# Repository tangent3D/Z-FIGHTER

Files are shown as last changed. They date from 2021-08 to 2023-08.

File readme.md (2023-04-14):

### Description
Z-FIGHTER is a Z80 hobby computer loosely based on [Grant Searle's CP/M on breadboard](http://searle.x10host.com/cpm/index.html "Grant Searle's CP/M on breadboard") project. As a fully assembled unit in its custom 3D-printed enclosure, Z-FIGHTER has a handheld-style form factor with front panel accessories intended for user-created software and games. Connected via serial to a computer or terminal, Z-FIGHTER can be used to enjoy a full CP/M 2.2 environment or Microsoft BASIC in ROM. Finally, a parallel port and external CPU control pins are provided to the user for hardware hacking and expansion.

### Specifications
- Z80 CPU @ 7.3728MHz
- CompactFlash interface for CP/M 2.2 operating system and file storage
- Z80 SIO/0 with dual 115200 bps RS-232 ports
- Jumper-selectable optional clock oscillator (X2) for SIO/0 port B (e.g.  614.4 KHz/64 for 9600 bps)
- Jumper-selectable RS-232 CTS flow control
- i8255 PPI-based parallel port reserved for front panel accessory daughterboard
- i8255 PPI-based user parallel port
- 512K ROM with external DIP-3 switches for manual ROM paging and ATF22V10C SPLD for memory map customization
- USB type-B power connector
- DS1233 supervisory circuit
- Optional jumpers to supply +5V to pin 9 on RS-232 ports (non-standard, for use at user's own risk)
- External CPU control header exposing #INT, #NMI, #WAIT, #RESET, system clock and SIO Ch. B clock signals

### Accessory board specifications
- 8x Cherry MX key switches
- ST7920 128x64 LCD module with software-controllable backlight
- Electromagnetic buzzer (CPU-controlled)

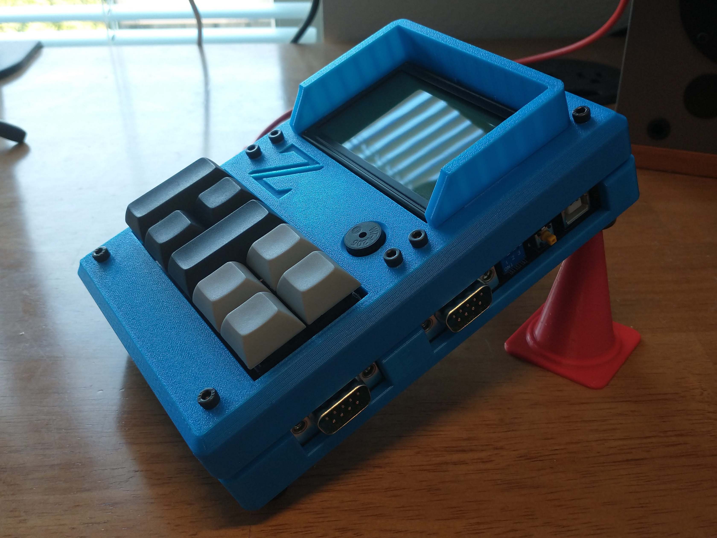
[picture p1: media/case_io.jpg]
Z-FIGHTER


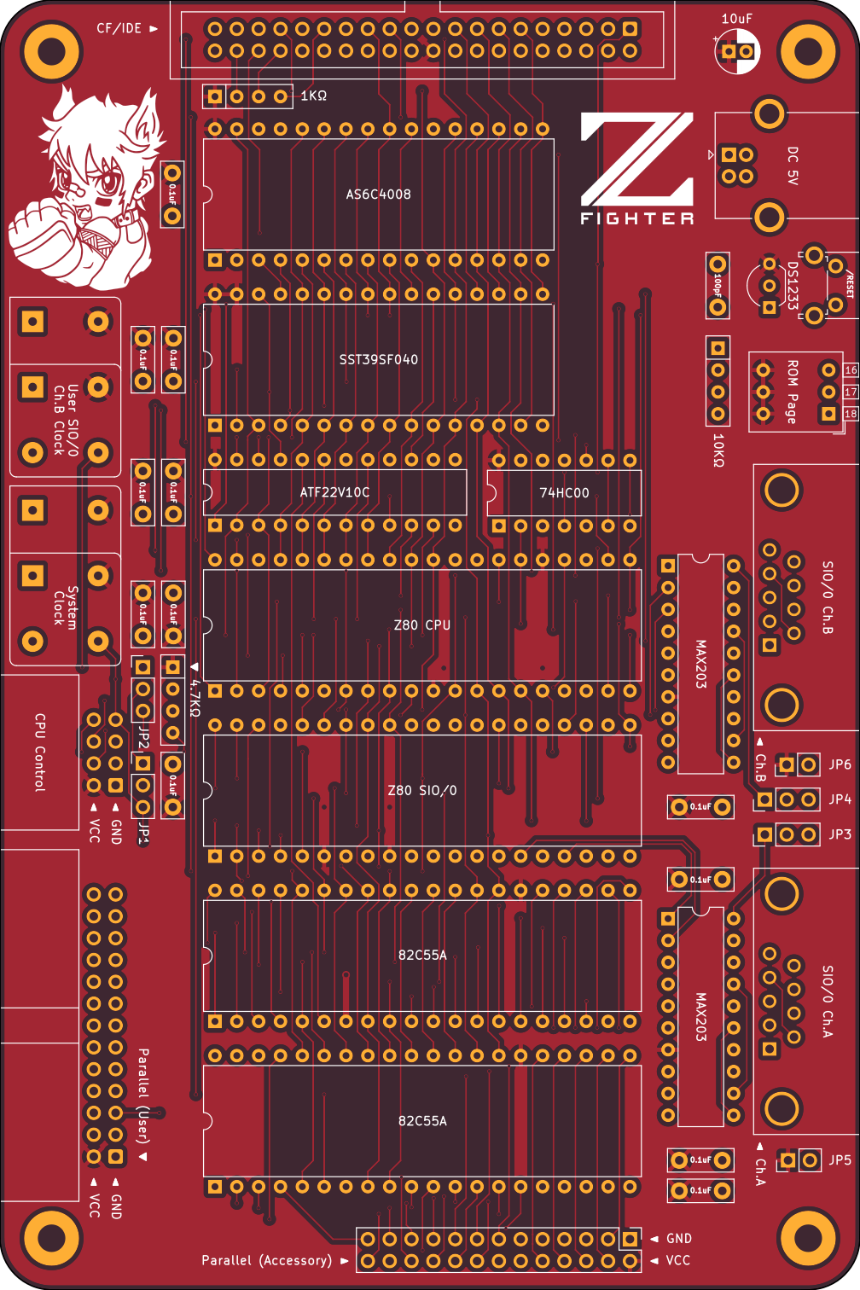
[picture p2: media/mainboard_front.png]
Z-FIGHTER Mainboard Z-FIGHTER mainboard


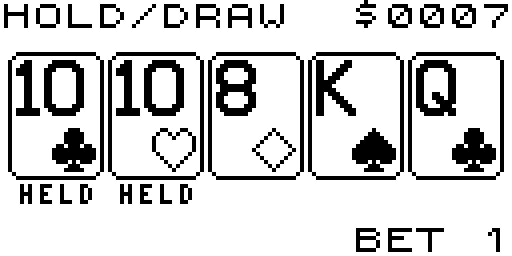
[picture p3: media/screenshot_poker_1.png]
Poker Z-FIGHTER poker game


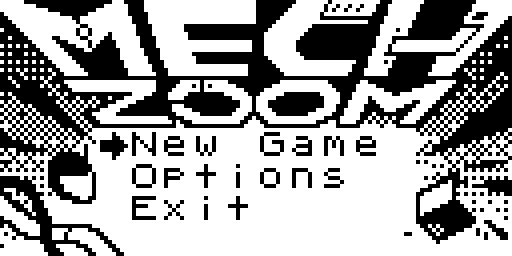
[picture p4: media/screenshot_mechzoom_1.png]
Mechzoom Z-FIGHTER 'Mechzoom' game


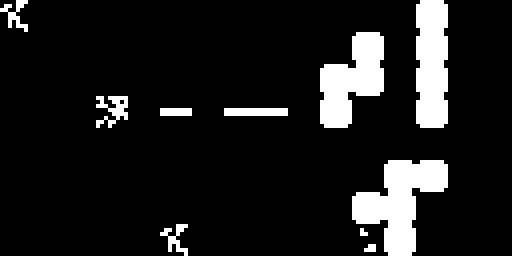
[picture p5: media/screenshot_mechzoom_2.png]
Mechzoom Z-FIGHTER 'Mechzoom' game


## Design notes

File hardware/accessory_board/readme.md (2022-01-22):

## Z-FIGHTER Front Panel Accessory Board

[PCB schematic](../../media/schematic_accessory_board.pdf)

[PCB layout](../../media/layout_accessory_board.pdf)

## Bill of Materials
|Part Description|Quantity|Mouser #|Link
|--|--|--|--|
|Cherry MX switches (PCB mount)|8|540-MX1A-G1NW|[Mouser](https://www.mouser.com/ProductDetail/?qs=F5EMLAvA7IAf8LDkSr80OA%3D%3D)
|Resistor Network 10K 9Pin Bussed|1|652-4609H-1LF-10K|[Mouser](https://www.mouser.com/ProductDetail/Bourns/4609H-101-103LF?qs=sGAEpiMZZMujMHSoaAZeGdkD0yBqu0zL)
|WT-1205 electromagnetic buzzer|1|539-PB1224PE-05Q|[Mouser](https://www.mouser.com/ProductDetail/?qs=yTNxYlKScpyeBlcw7zrVEw%3D%3D)
|1N5817 Schottky diode|1|511-1N5817|[Mouser](https://www.mouser.com/ProductDetail/?qs=JV7lzlMm3yKNnxZdh%252BSMnw%3D%3D)
|BC337 NPN transistor|2|512-BC33725TAR|[Mouser](https://www.mouser.com/ProductDetail/?qs=u2B728UsA6qKwH1IAisoWA%3D%3D)
|1/4W 820 Ohm 5% resistor|1|603-CFR-25JT-52-820R|[Mouser](https://www.mouser.com/ProductDetail/?qs=KUIzHt%2Fe91nf0zePCO9VQg%3D%3D)
|1/4W 680 Ohm 5% resistor|1|603-CFR-25JB-52-680R|[Mouser](https://www.mouser.com/ProductDetail/?qs=oypCK0zG327gSAdGYp%2FJTg%3D%3D)
|1x20 right angle header|1|649-1012937992002BLF|[Mouser](https://www.mouser.com/ProductDetail/?qs=0lQeLiL1qybxcF3pstck9w%3D%3D)
|ST7920 128x64 Graphic LCD|1||[BuyDisplay](https://www.buydisplay.com/3-3v-5v-graphic-display-128x64-serial-lcd-display-st7920)
|20mm vertical double row breakaway header|1||[Amazon](https://www.amazon.com/uxcell-Straight-Connector-Arduino-Prototype/dp/B07DJY3FRJ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)
|Right-angle header (female)|1||[Amazon](https://www.amazon.com/Yohii-Female-Header-2-54mm-Connector/dp/B07P1R9CGT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)
|DSA profile 2U keycap|2||[Pimp My Keyboard](https://pimpmykeyboard.com/dsa-2-space-pack-of-4/)
|DSA profile 1U keycap|6||[Pimp My Keyboard](https://pimpmykeyboard.com/dsa-1-space-pack-of-10/)
|Cherry PCB snap-in 2U stabilizer|2||[Amazon](https://www.amazon.com/dp/B085T8QZJC/ref=cm_sw_r_tw_dp_V3VNQRQ0CPQBPXNV3A6B?_encoding=UTF8&psc=1)

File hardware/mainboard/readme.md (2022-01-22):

## Z-FIGHTER Mainboard

[PCB schematic](../../media/schematic_mainboard.pdf)

[PCB layout](../../media/layout_mainboard.pdf)

## Bill of Materials
|Part Description|Quantity|Mouser #|Link
|--|--|--|--|
Z84C0008PEG Z80 CPU|1|692-Z84C0008PEG|[Mouser](https://www.mouser.com/ProductDetail/?qs=1C6%2FyOstnVvOWPsPt2TcAQ%3D%3D)
AS6C4008-55PCN 512K x8 SRAM|1|913-AS6C4008-55PCN|[Mouser](https://www.mouser.com/ProductDetail/?qs=E5c5%252Bmu3i3%252BMOyro1Tlhzg%3D%3D)
SST39SF040-70-4C-PHE 512K x8 EEPROM|1|804-39SF0407CPHE|[Mouser](https://www.mouser.com/ProductDetail/?qs=YClUa%252B2dcx1pgizrqJ6nyQ%3D%3D)
82C55A Programmable Peripheral Interface|2||[Jameco](https://www.jameco.com/z/82C55A-Major-Brands-IC-82C55A-CPU-PERIPHERAL-INTERFACE-8MHZ-DIP-40-pin_52417.html)
MAX203EPP +5V RS-232 Transceiver|2|700-MAX203EPPG36|[Mouser](https://www.mouser.com/ProductDetail/?qs=CDqwynd4ZNogpJr0Fmpb1w%3D%3D)
USB 2.0 RA Receptacle Type B|1|530-SS-52300-001|[Mouser](https://www.mouser.com/ProductDetail/?qs=gZXFycFWdAM098VuPZGg2w%3D%3D)
Resistor Network 10K 4Pin Bussed|1|652-4604X-1LF-10K|[Mouser](https://www.mouser.com/ProductDetail/?qs=jXOqZ2xt48NO%2FqYoJux7tg%3D%3D)
DE-9 R/A male connector|2|806-K22X-E9P-N-99|[Mouser](https://www.mouser.com/ProductDetail/?qs=SY6bF4iPirTJ1N%2FB520%252B5Q%3D%3D)
Resistor Network 1K 4Pin Bussed|1|652-4604X-1LF-1K|[Mouser](https://www.mouser.com/ProductDetail/?qs=xtl3rb8zXsvZ4tyOouOFIw%3D%3D)
Ceramic Disc Capacitor 100pF|1|594-D101K20Y5PL63L6R|[Mouser](https://www.mouser.com/ProductDetail/?qs=GtWgGqLahXfZ4CSgyYo67w%3D%3D)
40P 2R male vertical box header|1|538-70246-4004|[Mouser](https://www.mouser.com/ProductDetail/?qs=g5f4E6w8l8h7b35ebEIf2w%3D%3D)
Tactile Switches R/A 6X6 6.15mm BTN|1|653-B3F-3152|[Mouser](https://www.mouser.com/ProductDetail/?qs=Pjd0UV7BHP%252BLeRBK3ENKog%3D%3D)
Socket OSCILLATOR FULL 4PIN|2|535-1107741|[Mouser](https://www.mouser.com/ProductDetail/?qs=WZRMhwwaLl%2FApwqojhfzdA%3D%3D)
ATF22V10C EEPLD|1|556-AF22V10C15PU|[Mouser](https://www.mouser.com/ProductDetail/?qs=2mdvTlUeTfCr46ZvfjTtAg%3D%3D)
Supervisory Circuits 5V EconoReset|1|700-DS1233-5|[Mouser](https://www.mouser.com/ProductDetail/?qs=0Y9aZN%252BMVCWOcj0LQZHuFQ%3D%3D)
Standard Clock Oscillators DIP-14 5V 7.3728MHz|1|520-TCF737-X|[Mouser](https://www.mouser.com/ProductDetail/?qs=GxOUx7aO6nw6OhbIEx8owA%3D%3D)
SN74HC00|1|595-SN74HC00AN|[Mouser](https://www.mouser.com/ProductDetail/?qs=6ZVwTuetbD7YqMbSpl34ug%3D%3D)
Z84C4010PEG Z80 SIO/0|1|692-Z84C4010PEG|[Mouser](https://www.mouser.com/ProductDetail/?qs=ZNtr8jqNHF4vszdb5PeVGw%3D%3D)
.100 Shunt|4|200-SNT100BKGH|[Mouser](https://www.mouser.com/ProductDetail/?qs=92ilVni64gz8scrxywNMxw%3D%3D)
3 POS DIP switch R/A|1|490-DS02C-254-1L03BE|[Mouser](https://www.mouser.com/ProductDetail/?qs=wnTfsH77Xs4jkggh8giIBw%3D%3D)
Headers & Wire Housings 26P R/A|1|517-30326-5002|[Mouser](https://www.mouser.com/ProductDetail/?qs=QV10cN0MjFuwK57KknWtBg%3D%3D)
10uF radial electrolytic capacitor|1|667-ECA-1EM100I|[Mouser](https://www.mouser.com/ProductDetail/?qs=rMMd5vBiahoPyQAc8NWEpA%3D%3D)
Socket 40P DIP|4|649-DILB40P223TLF|[Mouser](https://www.mouser.com/ProductDetail/?qs=dNsYR%2FH0PyPZ7Cx3x%252BXI2w%3D%3D)
Socket 32P DIP|2|649-DILB32P223TLF|[Mouser](https://www.mouser.com/ProductDetail/?qs=dNsYR%2FH0PyPAfvGxulPprw%3D%3D)
Socket 20P DIP|2|517-4820-3004-CP|[Mouser](https://www.mouser.com/ProductDetail/?qs=IGgAdOvCTsThtp8UbkGeUw%3D%3D)
Socket 14P DIP|1|517-4814-3000-CP|[Mouser](https://www.mouser.com/ProductDetail/?qs=IGgAdOvCTsSwgxfUvPVZeg%3D%3D)
Socket 24P DIP|1|649-DILB24P-224TLF|[Mouser](https://www.mouser.com/ProductDetail/?qs=cTNRJjk9LRekdjb2T7GbOg%3D%3D)
Ceramic capacitor 0.1uF 50V 5mm|12|594-K104K15X7RF53H5|[Mouser](https://www.mouser.com/ProductDetail/?qs=sYfpZ29HcUSlgH5bSUHkYw%3D%3D)
Resistor Network 4.7K 4Pin Bussed|1|652-4604X-1LF-4.7K|[Mouser](https://www.mouser.com/ProductDetail/?qs=10P5Hhl%252BD79Zc7vt0%2Fhnuw%3D%3D)
26P 2R vertical female header|1|855-M20-7831346|[Mouser](https://www.mouser.com/ProductDetail/?qs=Jph8NoUxIfWtokGFIxN9SQ%3D%3D)
1x3P vertical pin header|4|649-68000-403H|[Mouser](https://www.mouser.com/ProductDetail/?qs=eanFghet1JNqC%2F0Iz%252BuUPw%3D%3D)
1x2P vertical pin header|2|649-68000-402HLF|[Mouser](https://www.mouser.com/ProductDetail/?qs=Jhn0v8ulSDtl9VR1zMrdxQ%3D%3D)
8P R/A male box header|1|710-61200821721|[Mouser](https://www.mouser.com/ProductDetail/?qs=PhR8RmCirEb56BXUsQNR%2FQ%3D%3D)
M3 standoff (20mm)|4||[Amazon](https://www.amazon.com/dp/B07PK23VC4/ref=cm_sw_r_tw_dp_NGRJ3TRHWGEE7J0RGDNS?_encoding=UTF8&psc=1)
M3 socket head cap screw|12||[Amazon](https://www.amazon.com/dp/B078V3YCF6/ref=cm_sw_r_tw_dp_TQ4HJWWVDEA1XZR15HDK?_encoding=UTF8&psc=1)
M3 nut|4||[Amazon](https://www.amazon.com/dp/B078V3YCF6/ref=cm_sw_r_tw_dp_TQ4HJWWVDEA1XZR15HDK?_encoding=UTF8&psc=1)
(Optional) M3 rubber feet (D12 x 10 x H7mm)|4||[Amazon](https://www.amazon.com/dp/B07LF1J7ZB/ref=cm_sw_r_tw_dp_JDTK9C1A8TC8FPBZZV7F?_encoding=UTF8&psc=1)

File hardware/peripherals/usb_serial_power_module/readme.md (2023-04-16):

USB serial adapter with software-controllable pin 9 +5V. Not adherent to RS-232 standard. For use with Z-FIGHTER only. 

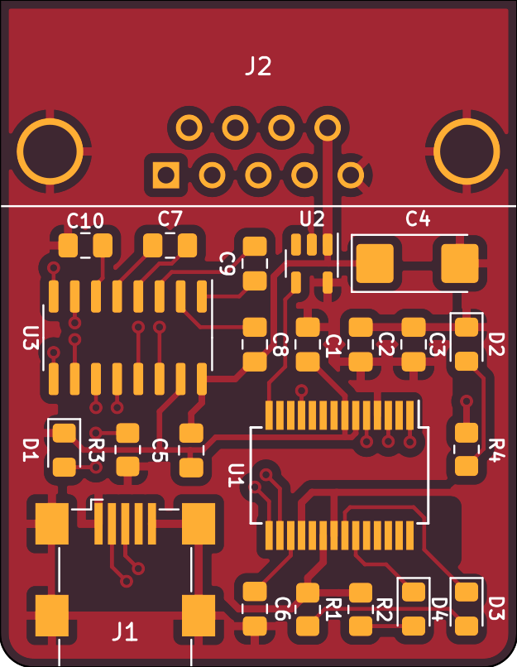
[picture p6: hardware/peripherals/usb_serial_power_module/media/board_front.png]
Module front


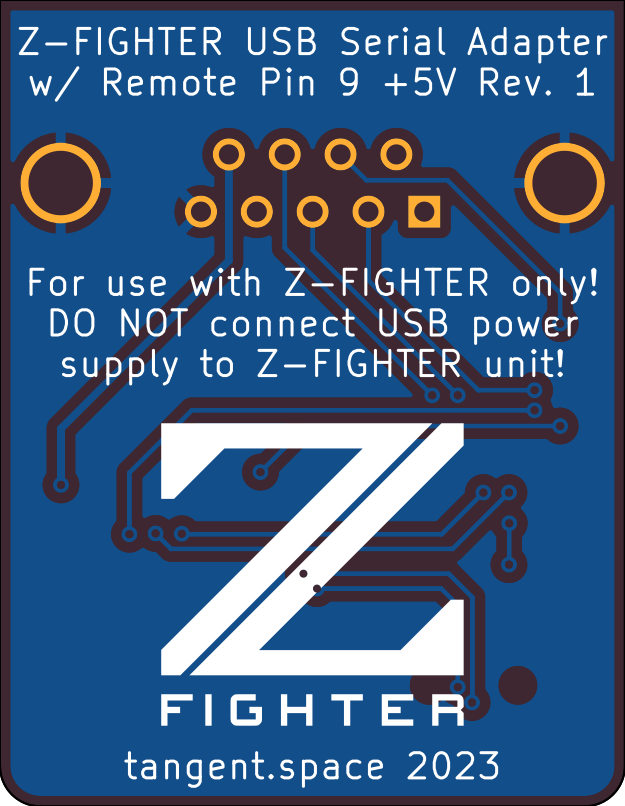
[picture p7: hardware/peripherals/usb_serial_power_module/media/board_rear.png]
Module rear


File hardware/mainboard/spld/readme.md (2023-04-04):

## Z-FIGHTER's Programmable Logic Device

An Atmel ATF22V10C-15PU SPLD is responsible for producing all chip select logic for Z-FIGHTER. An EEPROM burner is required to program the SPLD with a fuse map.

By default, Z-FIGHTER's memory map is configured as 32K ROM (0000h-7FFFh) and 32K RAM (8000h-FFFFh). ROM is disabled when an I/O write is executed on port 38h. RAM will thereafter use the entire 64K memory map until system reset.

A 3-position DIP switch (connected to EEPROM A18, A17, A16) will manually page the 512K EEPROM, affording the user eight bootable ROMs to be installed on the system. All ROMS should be placed at base addresses of 0000h, 10000h, ..., 70000h.

__Note for advanced users:__ The aforementioned DIP switch is likewise connected to the SPLD. Using combinational logic with EEPROM A18-A16 and Z80 address bus lines A15-A13, custom memory maps per each selected EEPROM page can be defined in chunks of 8K, e.g. 56K ROM/8K RAM.[^1] Care should be taken that ROMs are compiled to use the intended memory map.

Fuse maps can be compiled using [GALasm](https://github.com/daveho/GALasm).

[^1]: Mainboard revision 2d and later. In prior revisions, line A13 is not connected as an SPLD input.

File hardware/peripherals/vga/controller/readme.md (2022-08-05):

## Z-FIGHTER VGA Controller

[Project Notes](https://tangent.space/vga.htm)

[PCB schematic](../../../../media/schematic_vga_controller.pdf)

[PCB layout (Front)](../../../../media/layout_vga_controller_front.pdf)

[PCB layout (Back)](../../../../media/layout_vga_controller_back.pdf)

## Bill of Materials
|Reference|Description|Mouser #|Link
|--|--|--|--|
U1|74HC241||
R1,R2|Resistor, 1KΩ, 1/4W||
RN1,RN2|Resistor Array, Bussed, 10KΩ, 4x, SIP-5||
C1|Capacitor, 0.1uF, 5mm||
Q1|BC547, TO-92||
SW1 - SW8|Switch, Omron B3F-4050||
J1|DE-9, Female, R/A||

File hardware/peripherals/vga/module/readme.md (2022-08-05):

## Z-FIGHTER VGA Module

[Project Notes](https://tangent.space/vga.htm)

[PCB schematic](../../../../media/schematic_vga_module.pdf)

[PCB layout](../../../../media/layout_vga_module.pdf)

## Bill of Materials
|Reference|Description|Mouser #|Link
|--|--|--|--|
U1,U2|74HC4040||
U3,U4|GAL16V8||
U5,U6,U12,U13,U14|74HC541||
U7|74HC00||
U8|74HC04||
U9|74HC74||
U10|74HC165||
U11|AS6C6264||
X1|25.175 MHz Oscillator, DIP8/DIP14||
Q1|BC547, TO-92||
R1 - R3|220Ω Resistor, 1/4W||
R4 - R8|75Ω Resistor, 1/4W||
R9,R10|1KΩ Resistor, 1/4W||
C1,C2,C3,C6,C7|470pF Capacitor, Ceramic, 5mm||
C4,C5|22pF Capacitor, Ceramic, 5mm||
C8 - C22|0.1uF Capacitor, Ceramic, 5mm||
J1|26P Female Header, Vertical||
J2|8P Female Header, Vertical||
J3|DE-15 Female R/A||
J4,J5|DE-9 Male R/A||
SW1|DIP Switch, 3x, 7.62mm||
JP1|Jumper, 2.54mm, Vertical||




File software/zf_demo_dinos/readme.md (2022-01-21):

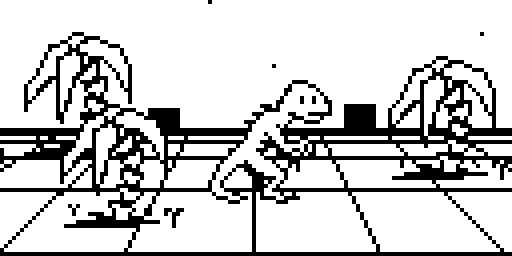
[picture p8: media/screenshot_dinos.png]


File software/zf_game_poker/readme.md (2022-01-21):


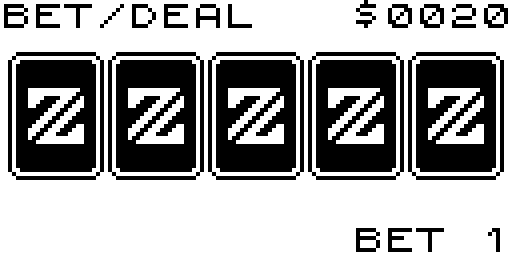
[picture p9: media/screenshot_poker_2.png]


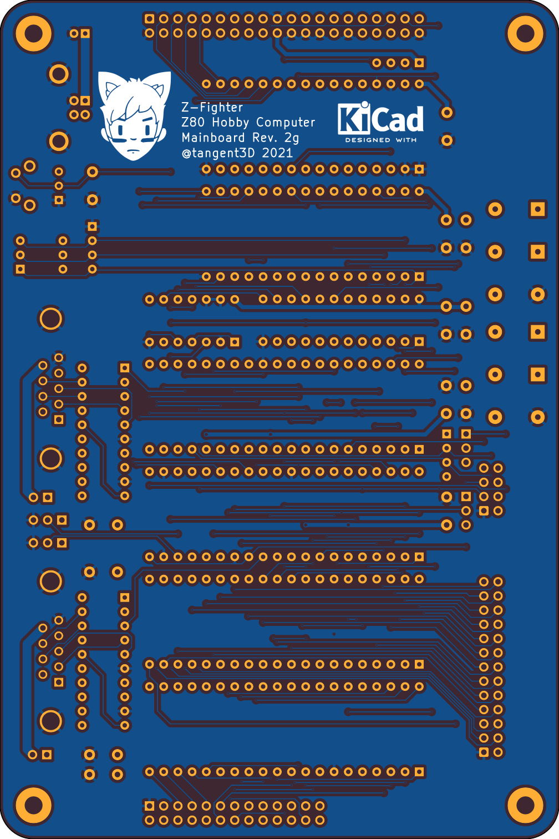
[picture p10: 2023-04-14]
media/mainboard_rear.png

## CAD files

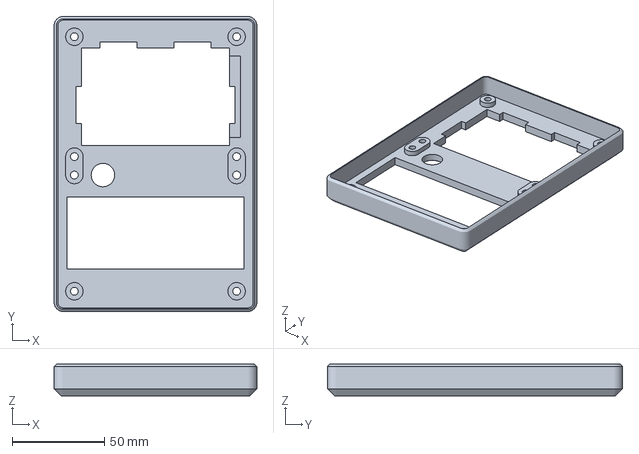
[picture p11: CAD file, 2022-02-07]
hardware/case/3mf/Z-FIGHTER_Case_Front.3mf
110.0 x 160.0 x 17.2 mm

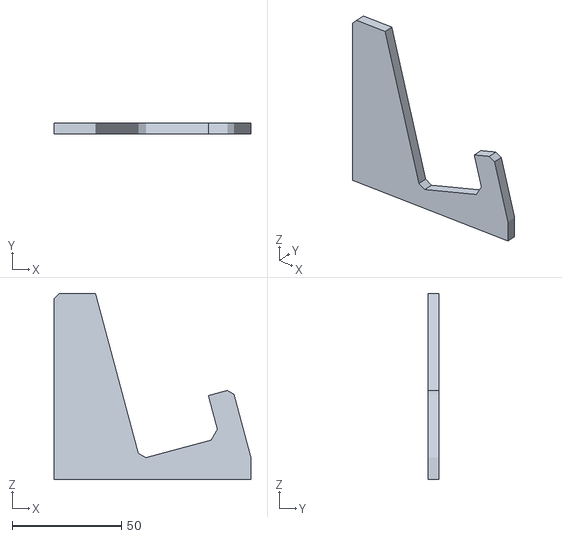
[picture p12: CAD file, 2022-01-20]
hardware/case/stl/Z-FIGHTER_Stand_Side.STL
90.0 x 5.00 x 85.0

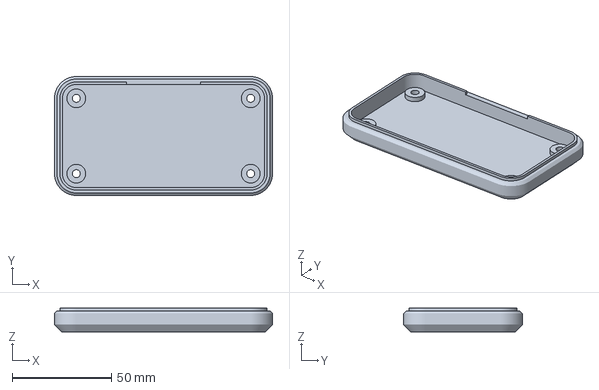
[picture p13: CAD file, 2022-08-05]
hardware/peripherals/vga/controller/case/3mf/Z-FIGHTER_Controller_Rear.3mf
110.0 x 60.0 x 12.1 mm

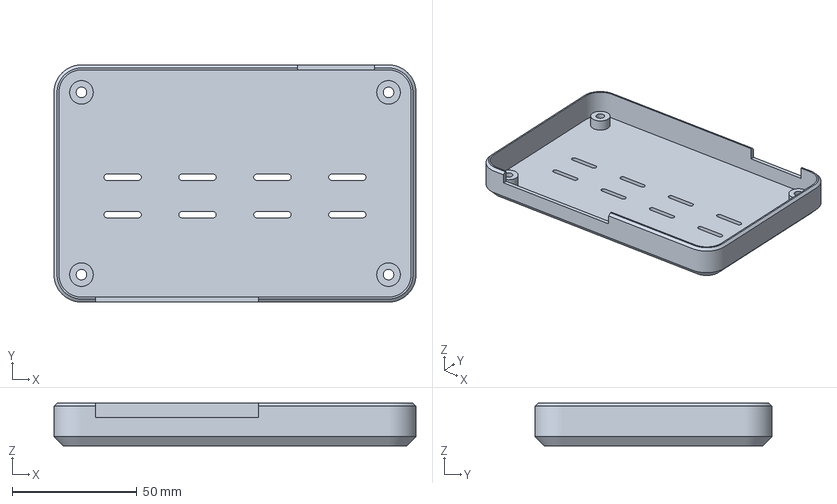
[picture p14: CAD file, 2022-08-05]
hardware/peripherals/vga/module/case/3mf/Z-FIGHTER_VGA_Front.3mf
145.0 x 95.0 x 17.2 mm

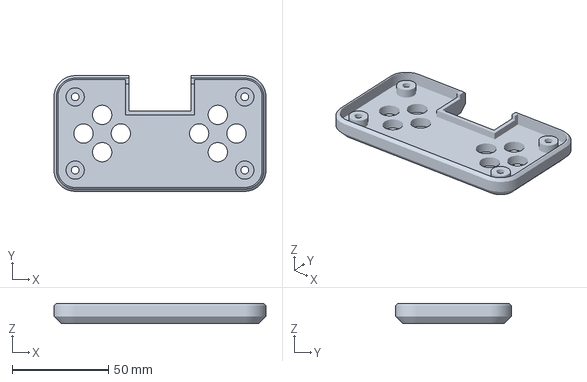
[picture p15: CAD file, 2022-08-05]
hardware/peripherals/vga/controller/case/3mf/Z-FIGHTER_Controller_Front.3mf
110.0 x 60.0 x 10.6 mm

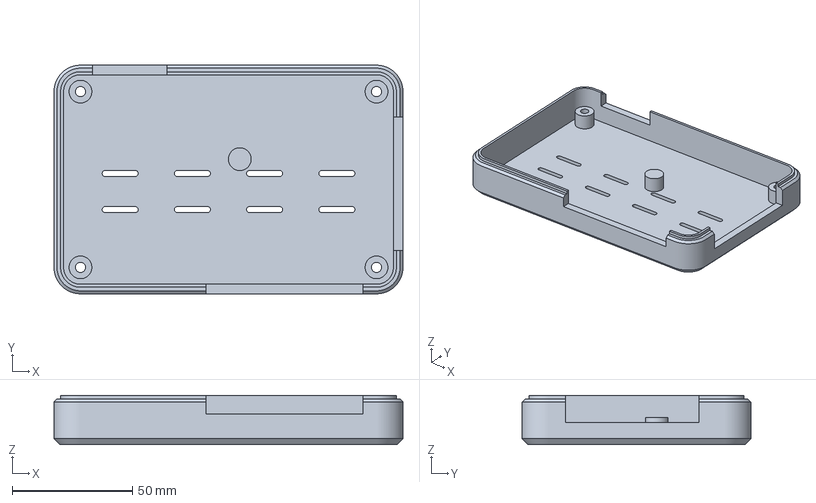
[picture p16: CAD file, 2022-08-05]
hardware/peripherals/vga/module/case/3mf/Z-FIGHTER_VGA_Rear.3mf
145.0 x 95.0 x 20.5 mm

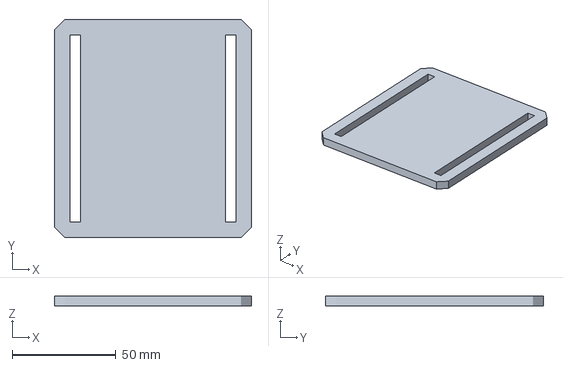
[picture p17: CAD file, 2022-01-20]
hardware/case/3mf/Z-FIGHTER_Stand_Base.3mf
95.0 x 105.0 x 5.00 mm

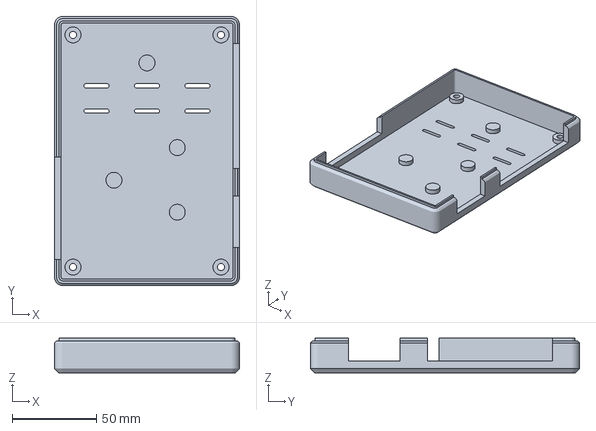
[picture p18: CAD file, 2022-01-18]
hardware/case/3mf/Z-FIGHTER_Case_Rear.3mf
110.0 x 160.0 x 20.5 mm

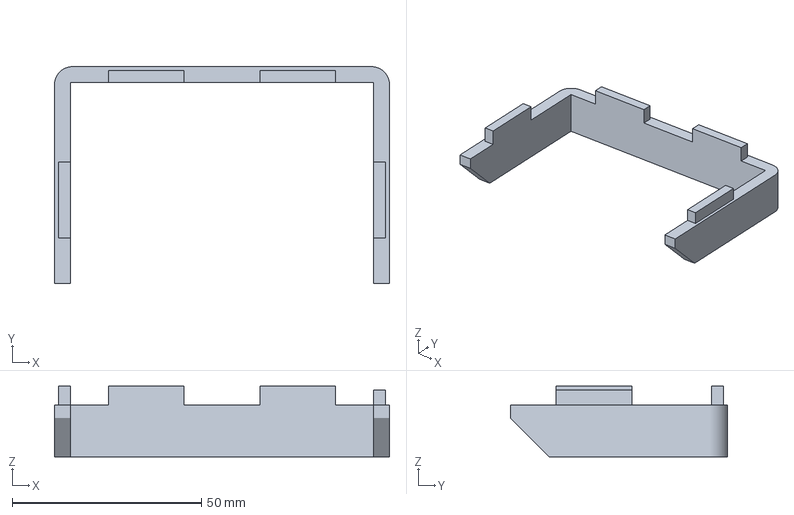
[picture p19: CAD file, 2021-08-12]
hardware/case/3mf/Z-FIGHTER_Case_Shroud.3mf
88.5 x 57.3 x 18.7 mm

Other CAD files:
hardware/case/3mf/Z-FIGHTER_Stand_SideB_.3mf
hardware/case/3mf/Z-FIGHTER_Stand_SideA_.3mf
hardware/case/stl/Z-FIGHTER_Case_Front.STL
hardware/case/stl/Z-FIGHTER_Case_Rear.STL
hardware/case/stl/Z-FIGHTER_Case_Shroud.STL
hardware/case/stl/Z-FIGHTER_Stand_Base.STL
hardware/peripherals/vga/controller/case/stl/Z-FIGHTER_Controller_Front.STL
hardware/peripherals/vga/controller/case/stl/Z-FIGHTER_Controller_Rear.STL
hardware/peripherals/vga/module/case/stl/Z-FIGHTER_VGA_Front.STL
hardware/peripherals/vga/module/case/stl/Z-FIGHTER_VGA_Rear.STL

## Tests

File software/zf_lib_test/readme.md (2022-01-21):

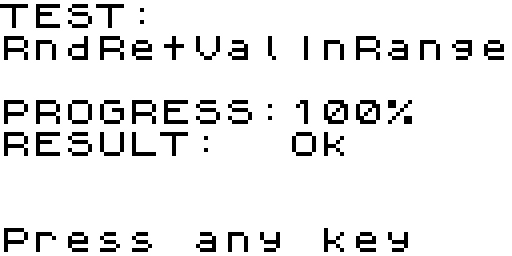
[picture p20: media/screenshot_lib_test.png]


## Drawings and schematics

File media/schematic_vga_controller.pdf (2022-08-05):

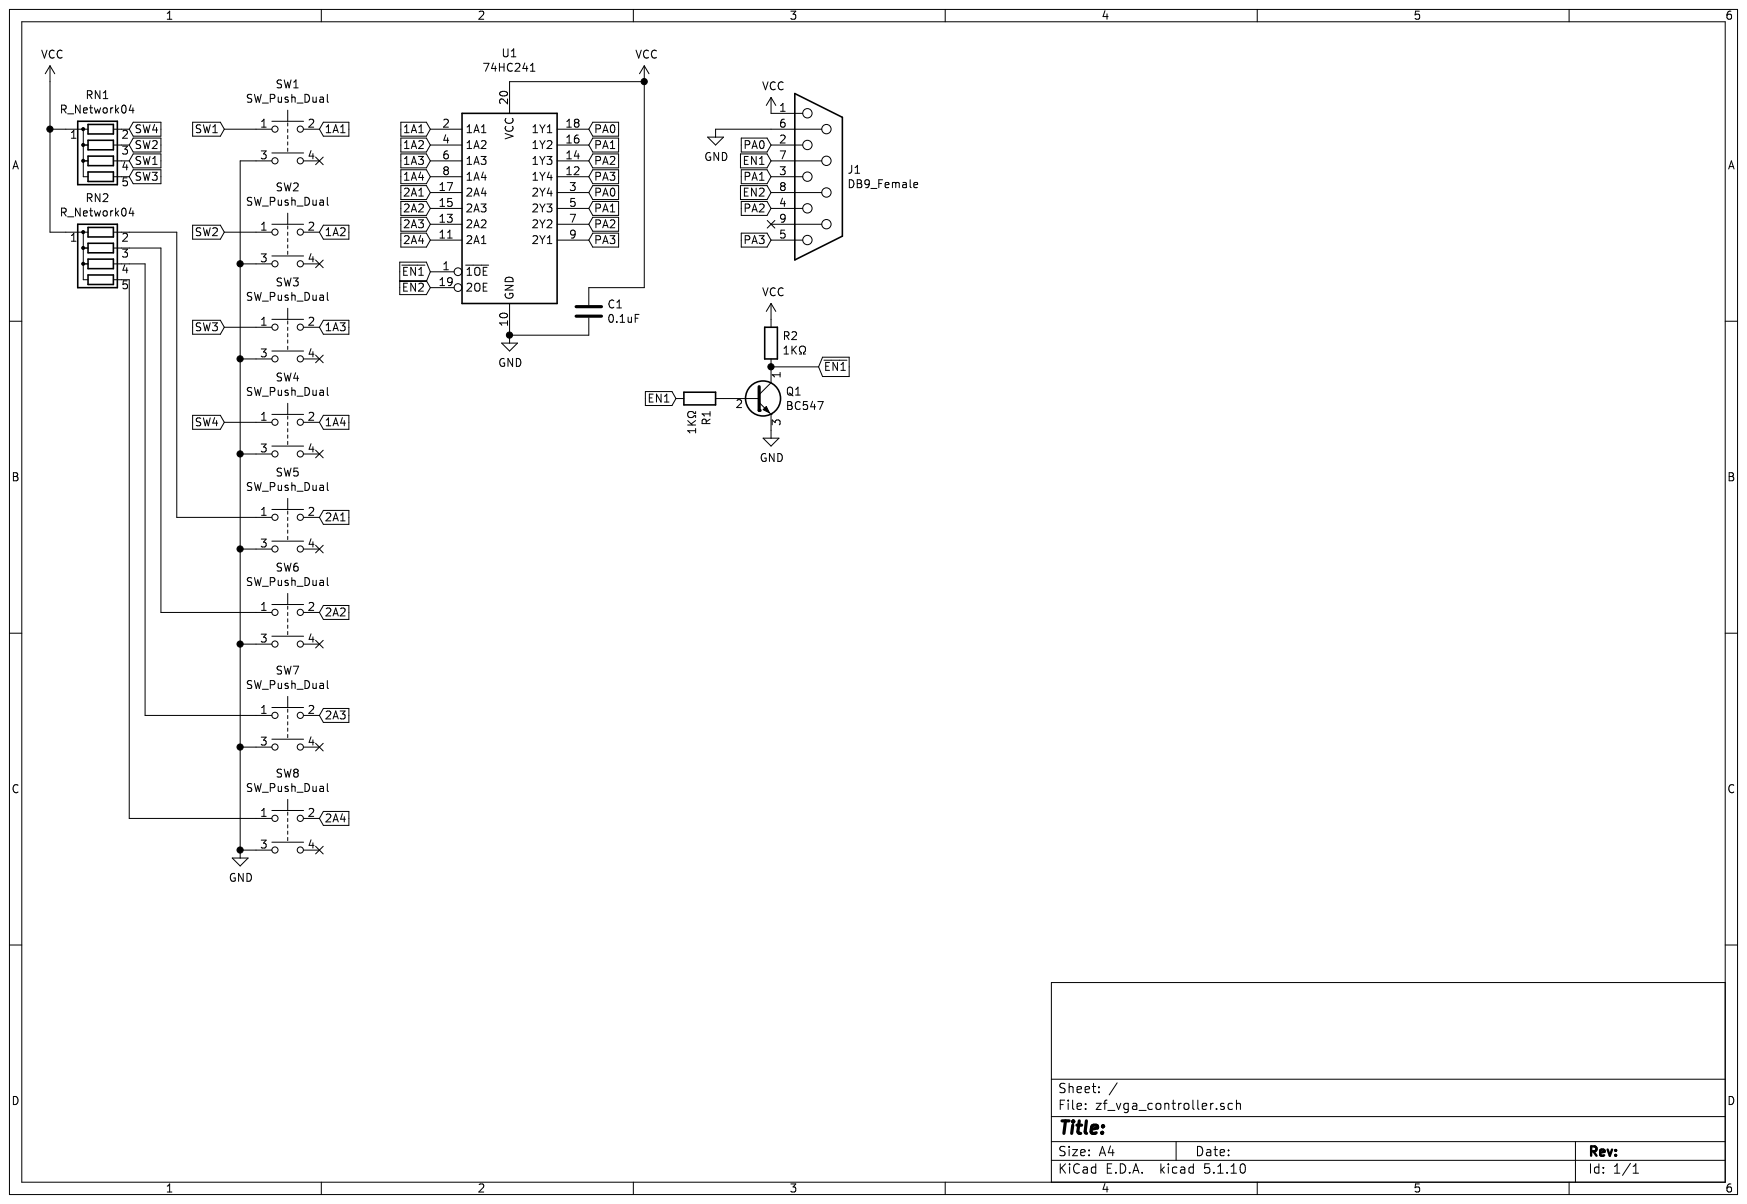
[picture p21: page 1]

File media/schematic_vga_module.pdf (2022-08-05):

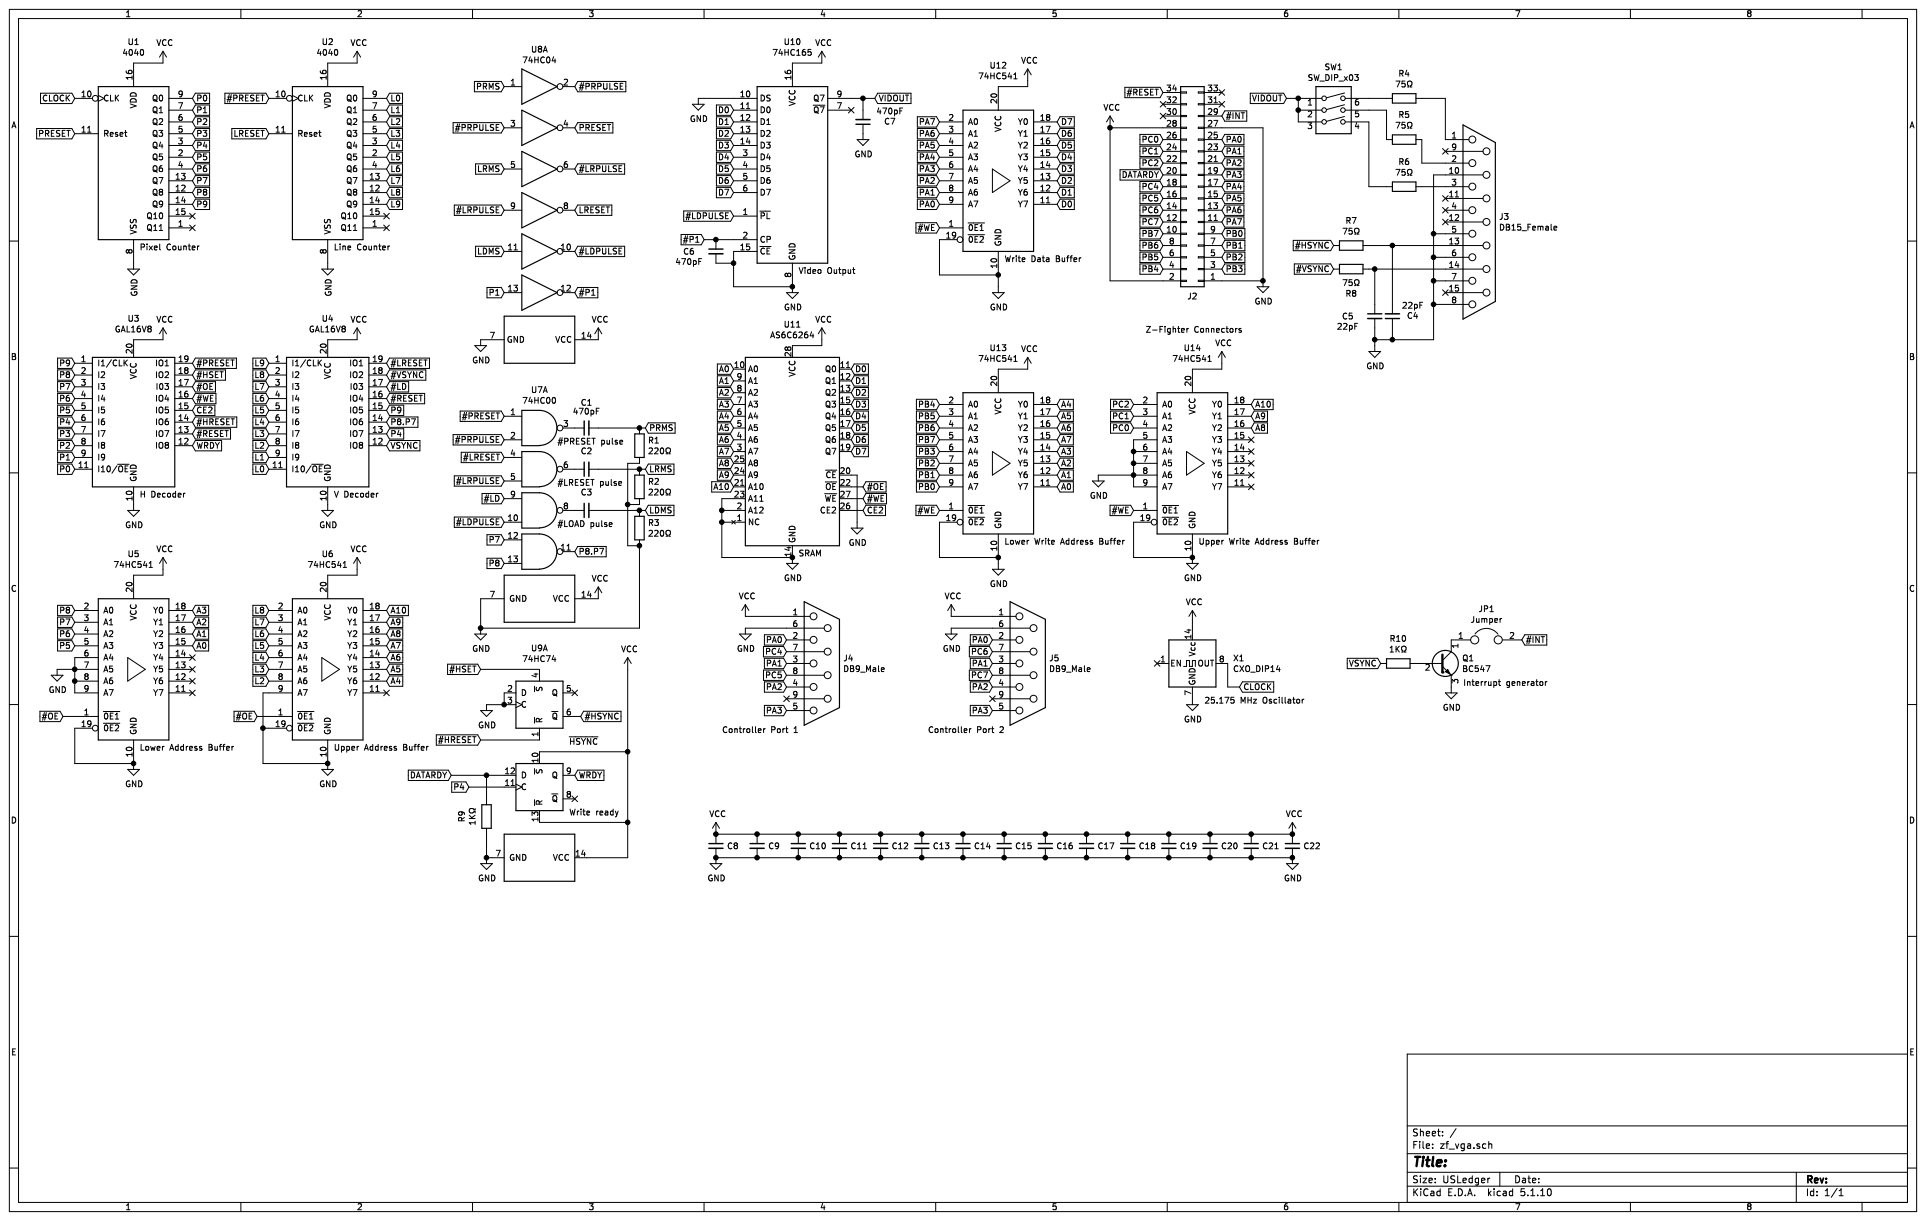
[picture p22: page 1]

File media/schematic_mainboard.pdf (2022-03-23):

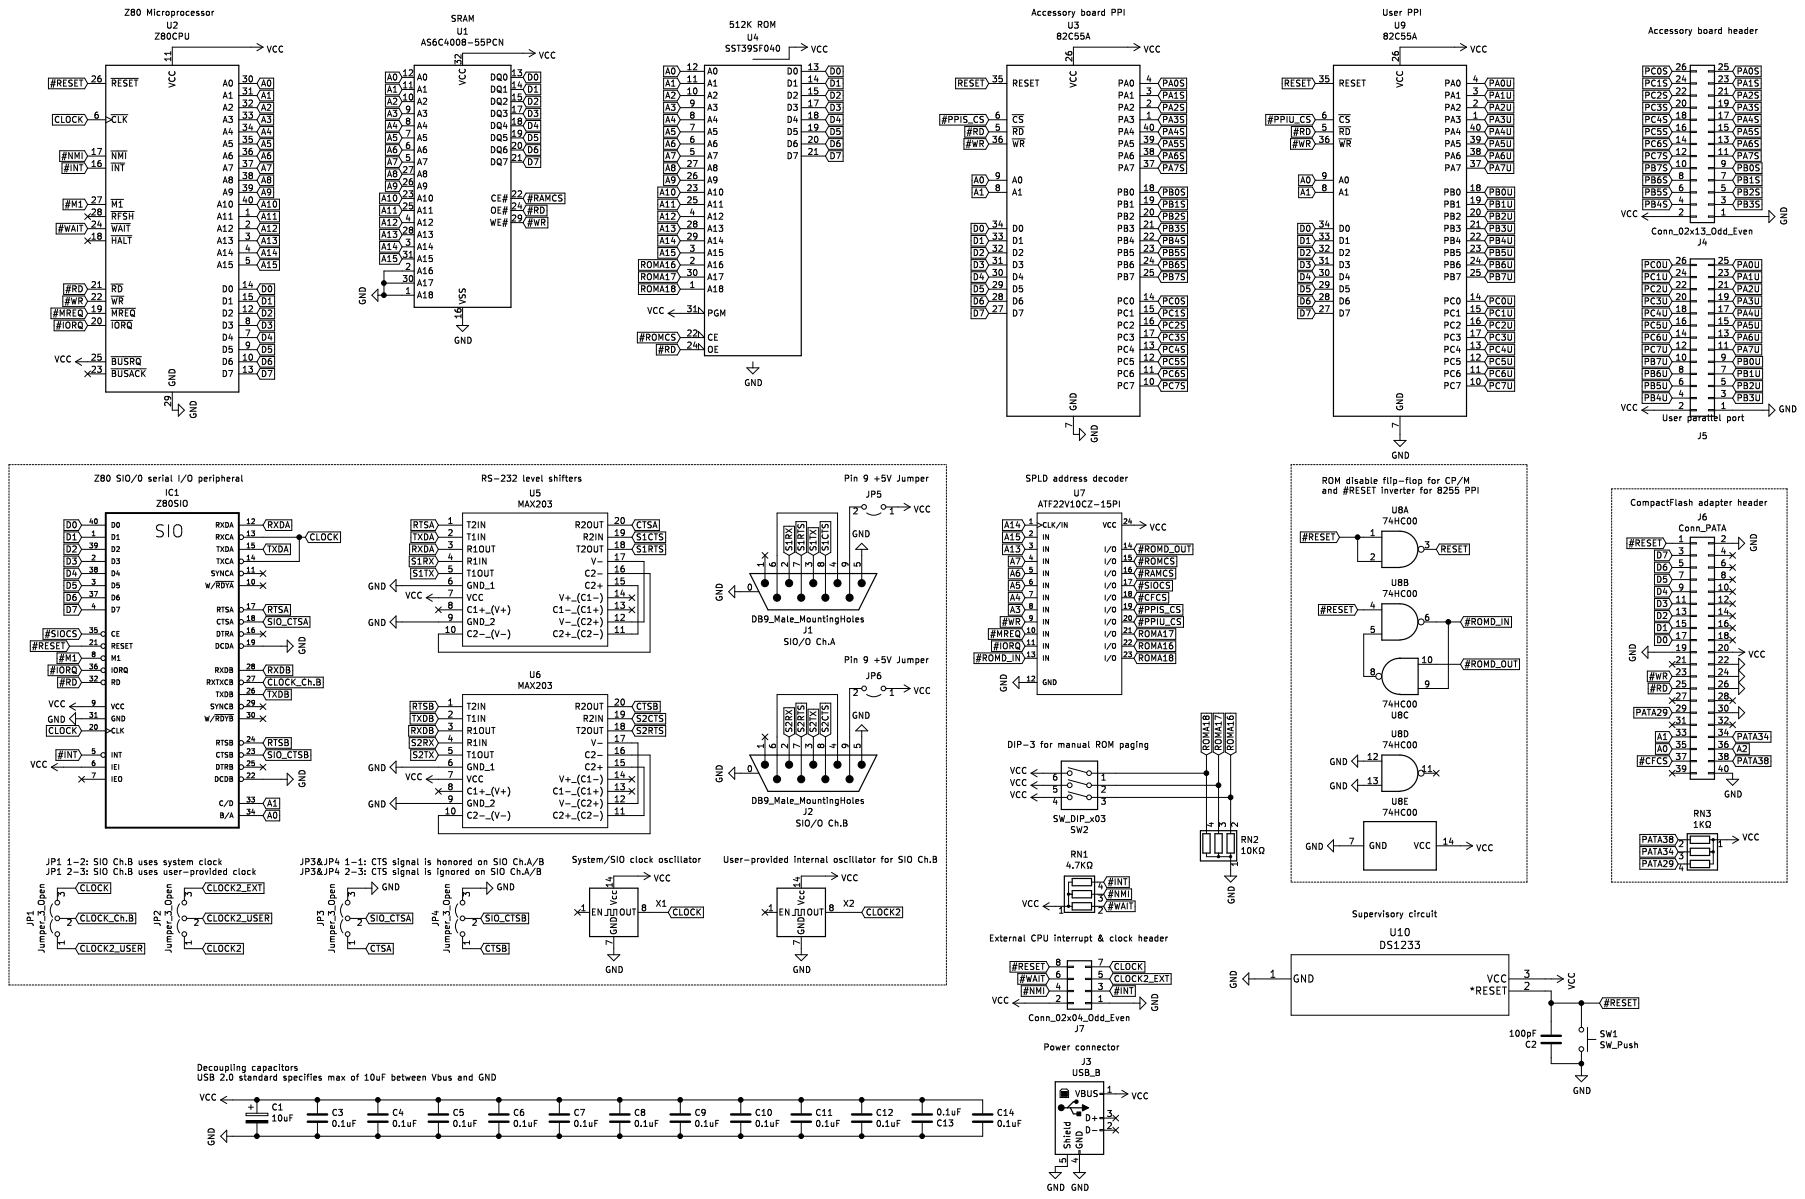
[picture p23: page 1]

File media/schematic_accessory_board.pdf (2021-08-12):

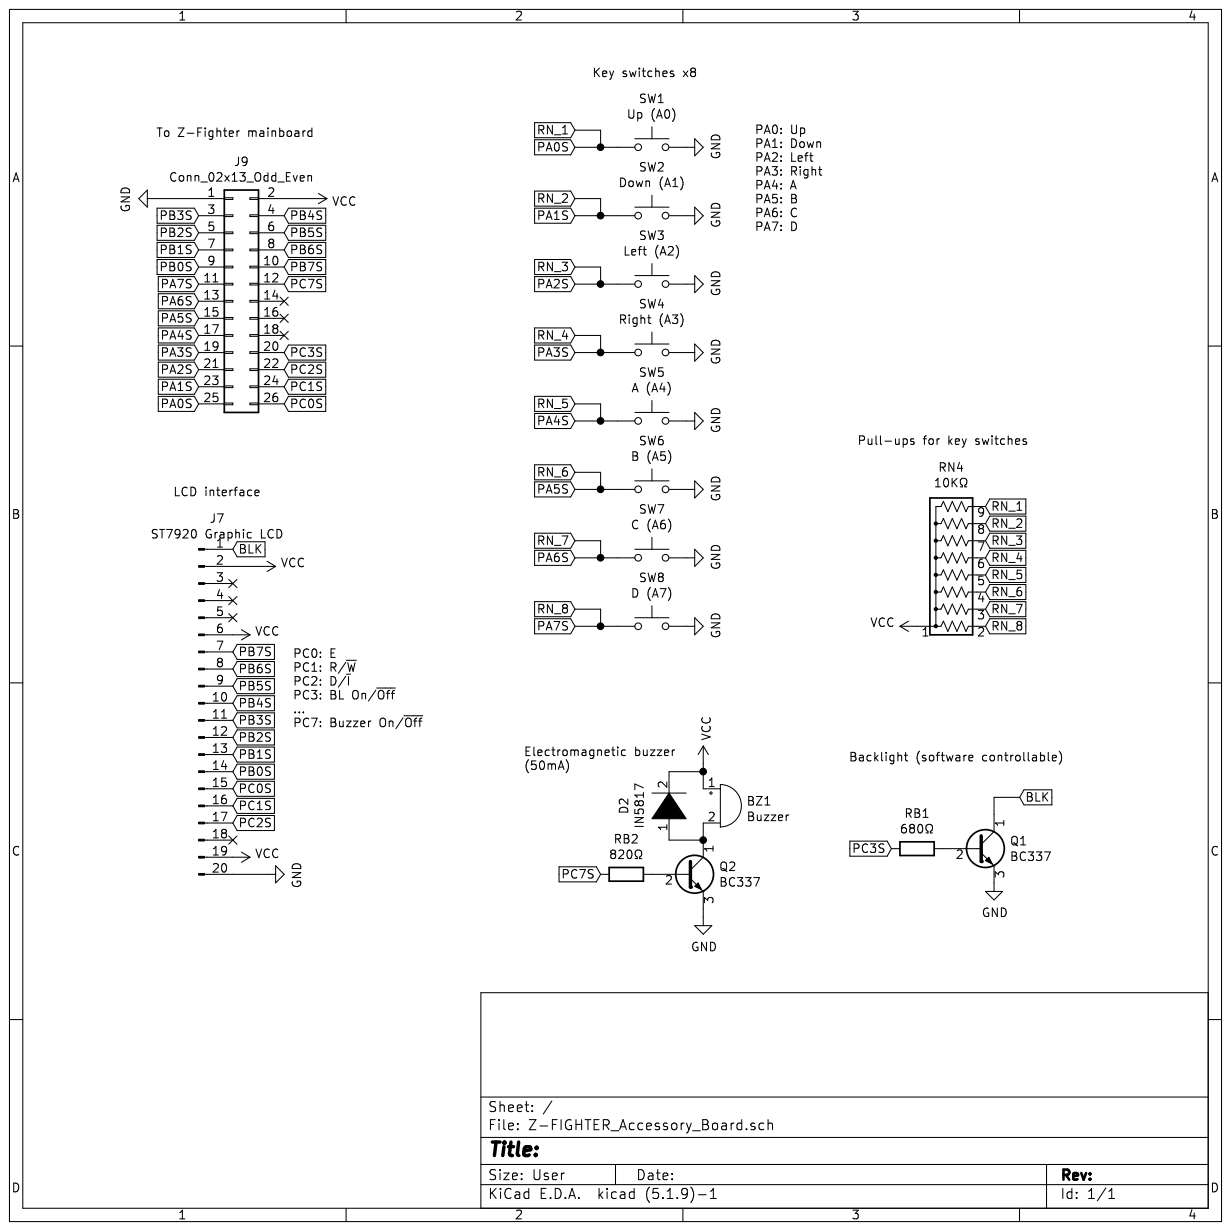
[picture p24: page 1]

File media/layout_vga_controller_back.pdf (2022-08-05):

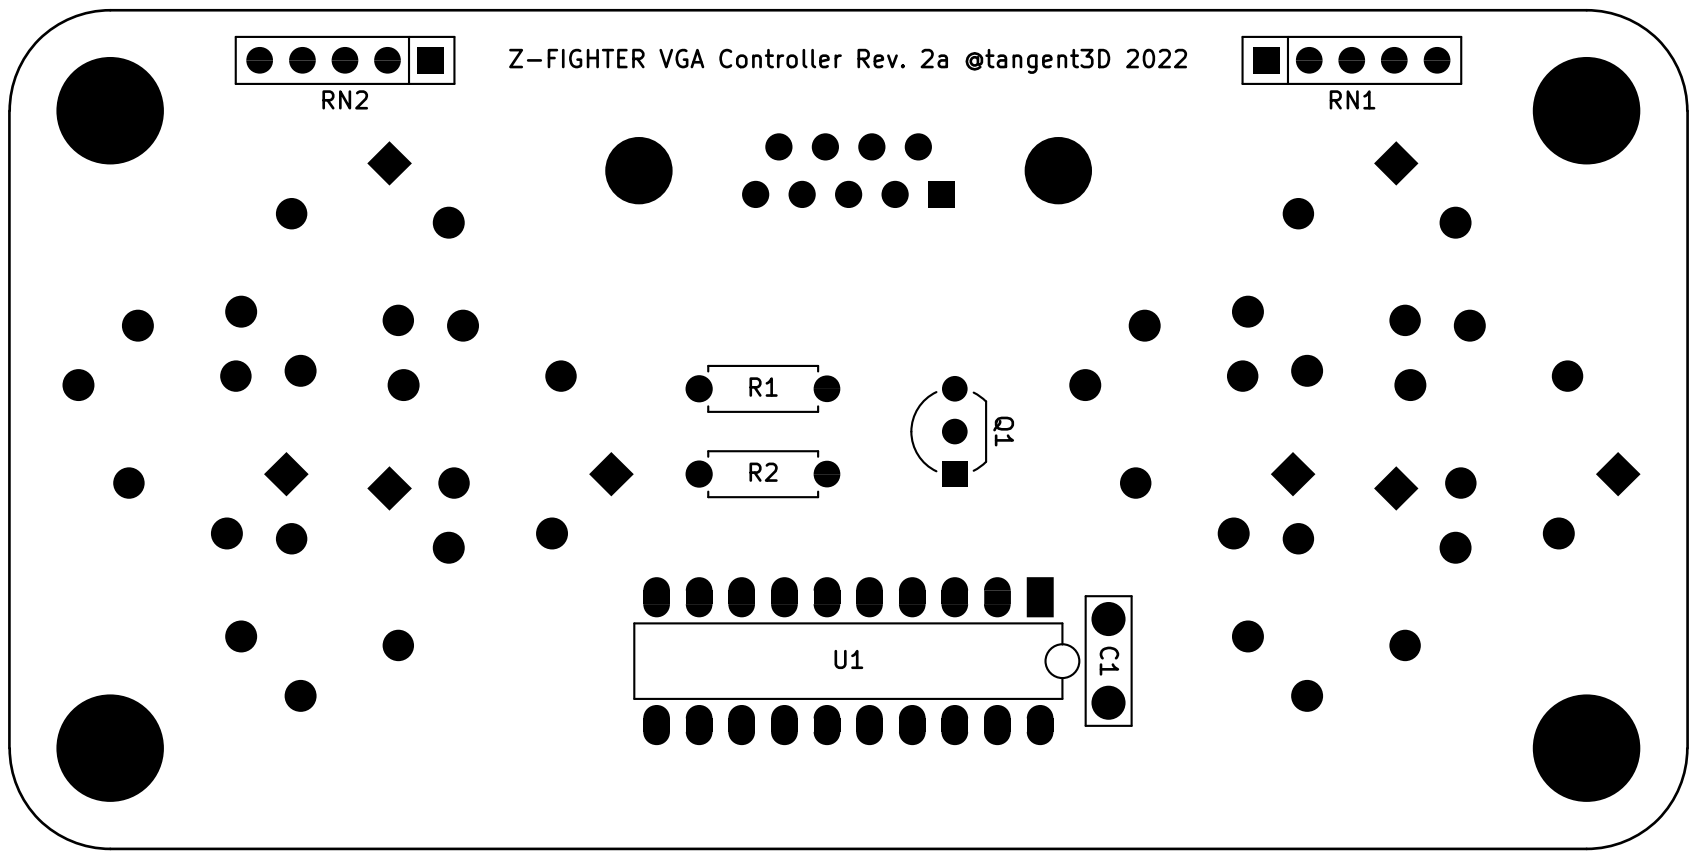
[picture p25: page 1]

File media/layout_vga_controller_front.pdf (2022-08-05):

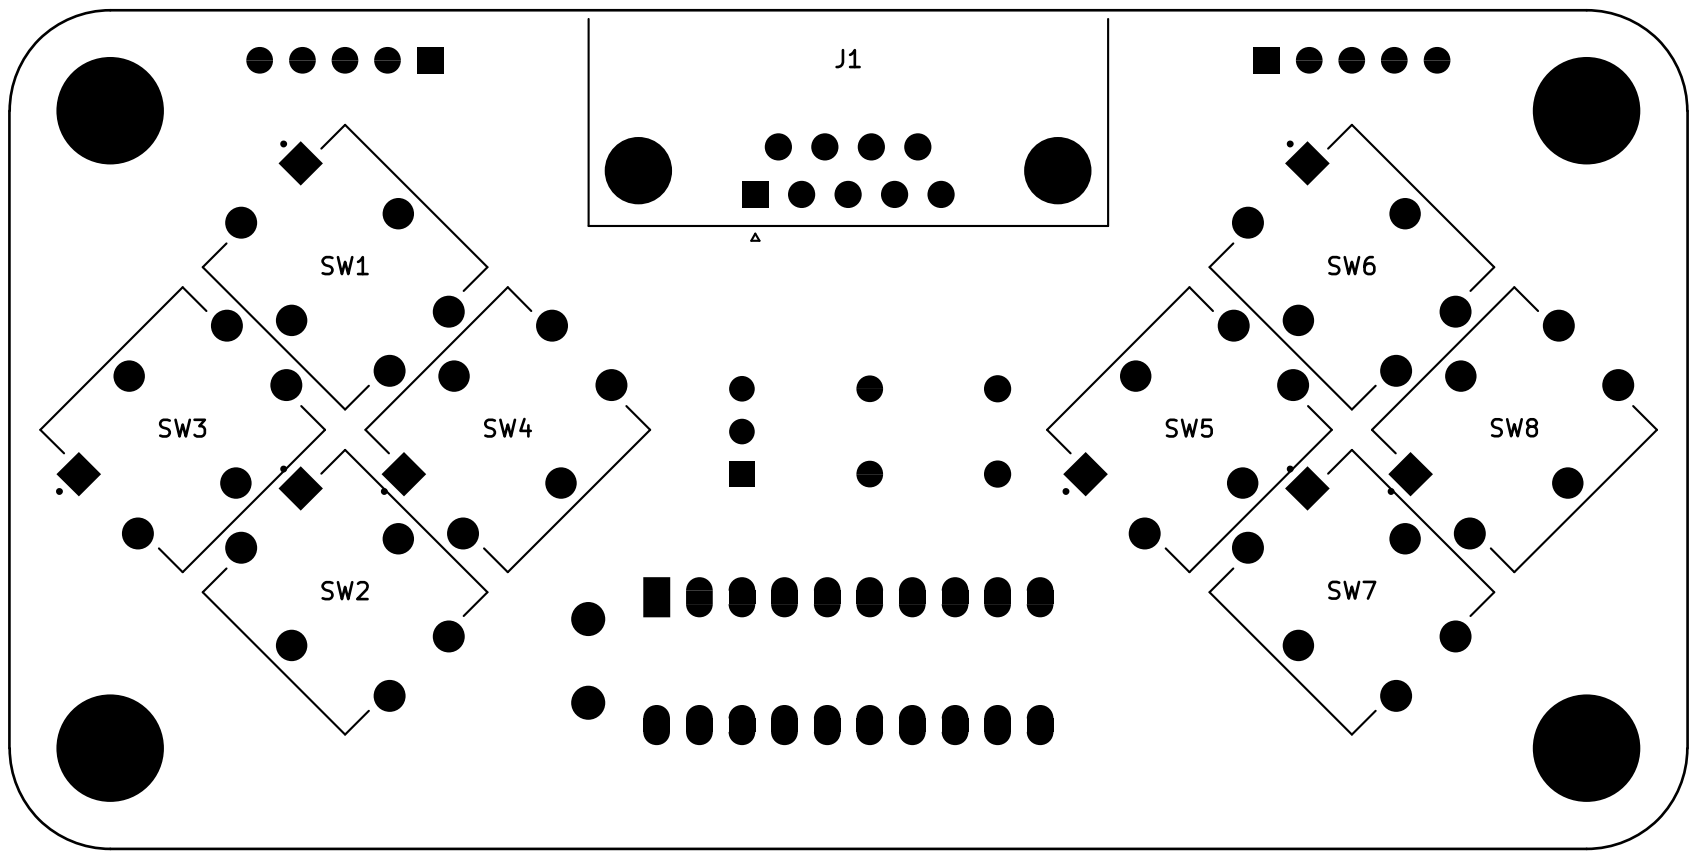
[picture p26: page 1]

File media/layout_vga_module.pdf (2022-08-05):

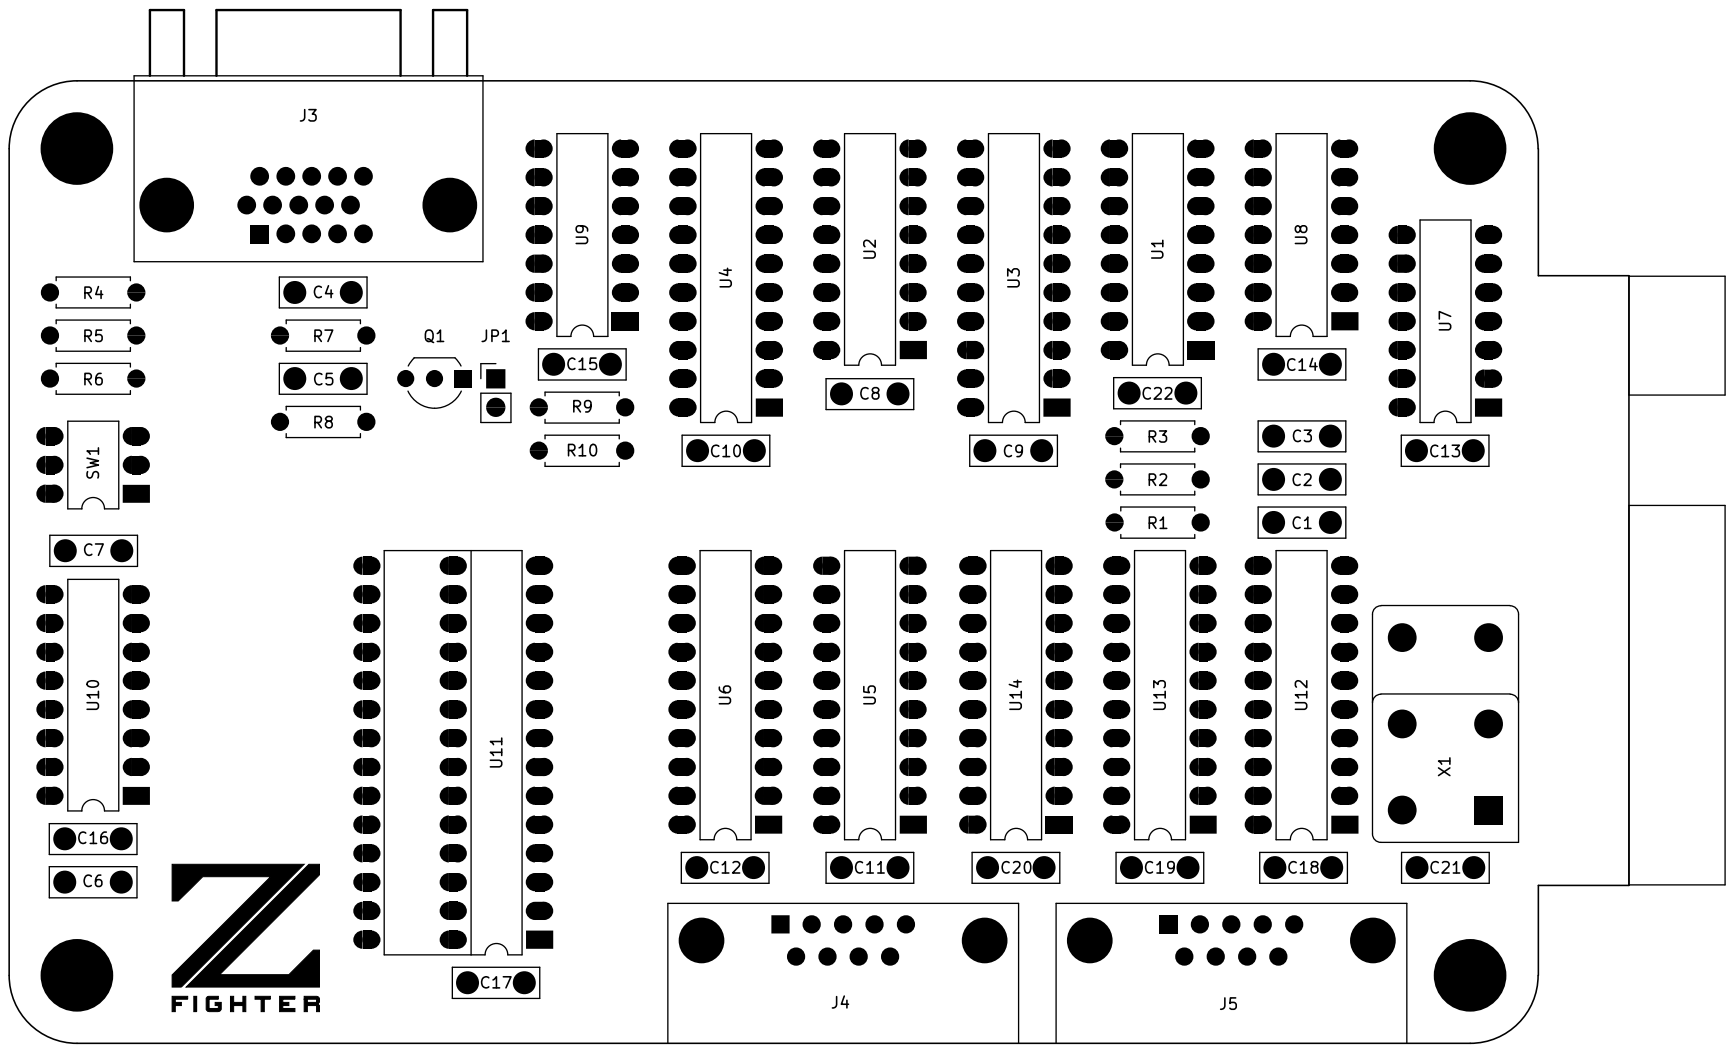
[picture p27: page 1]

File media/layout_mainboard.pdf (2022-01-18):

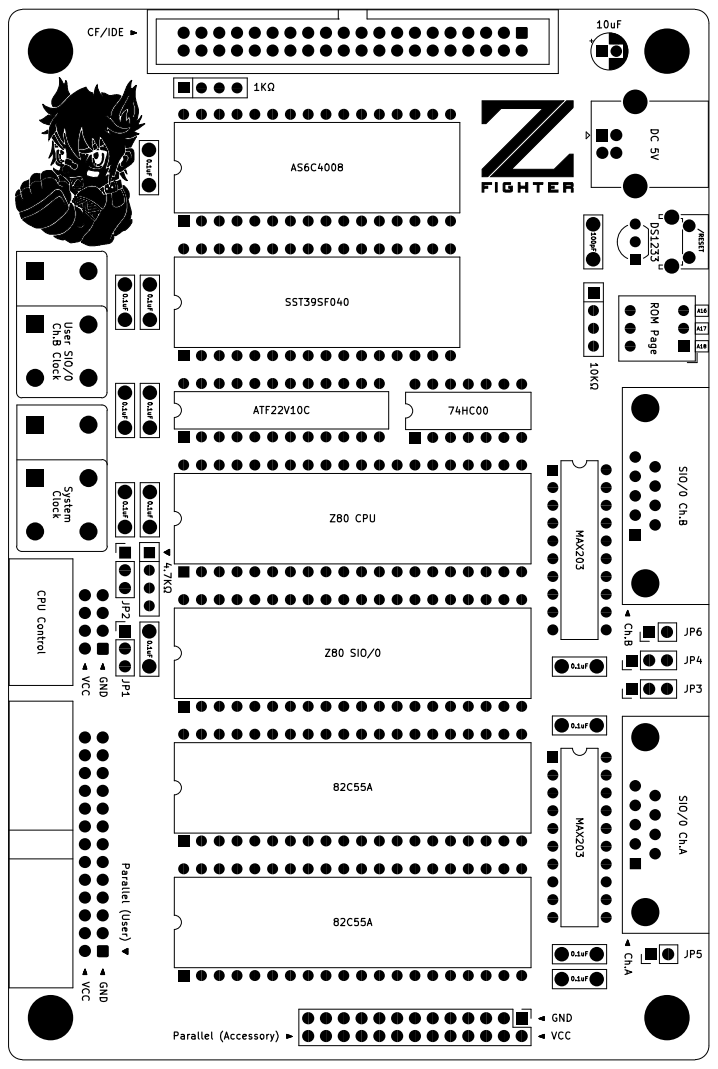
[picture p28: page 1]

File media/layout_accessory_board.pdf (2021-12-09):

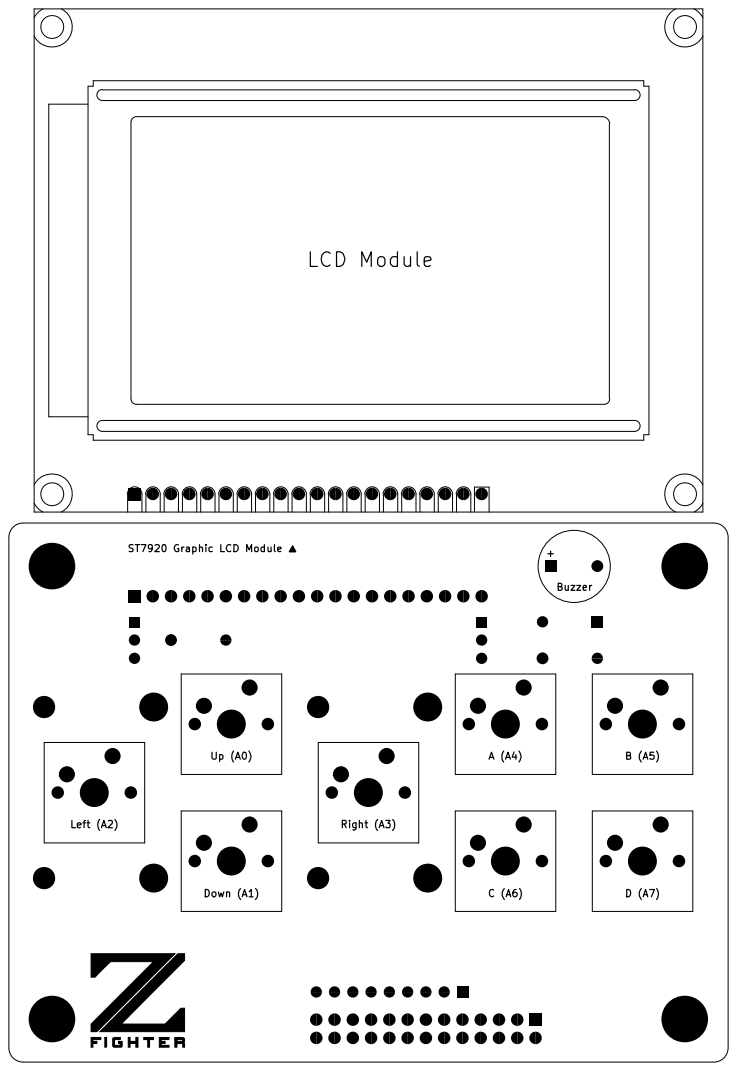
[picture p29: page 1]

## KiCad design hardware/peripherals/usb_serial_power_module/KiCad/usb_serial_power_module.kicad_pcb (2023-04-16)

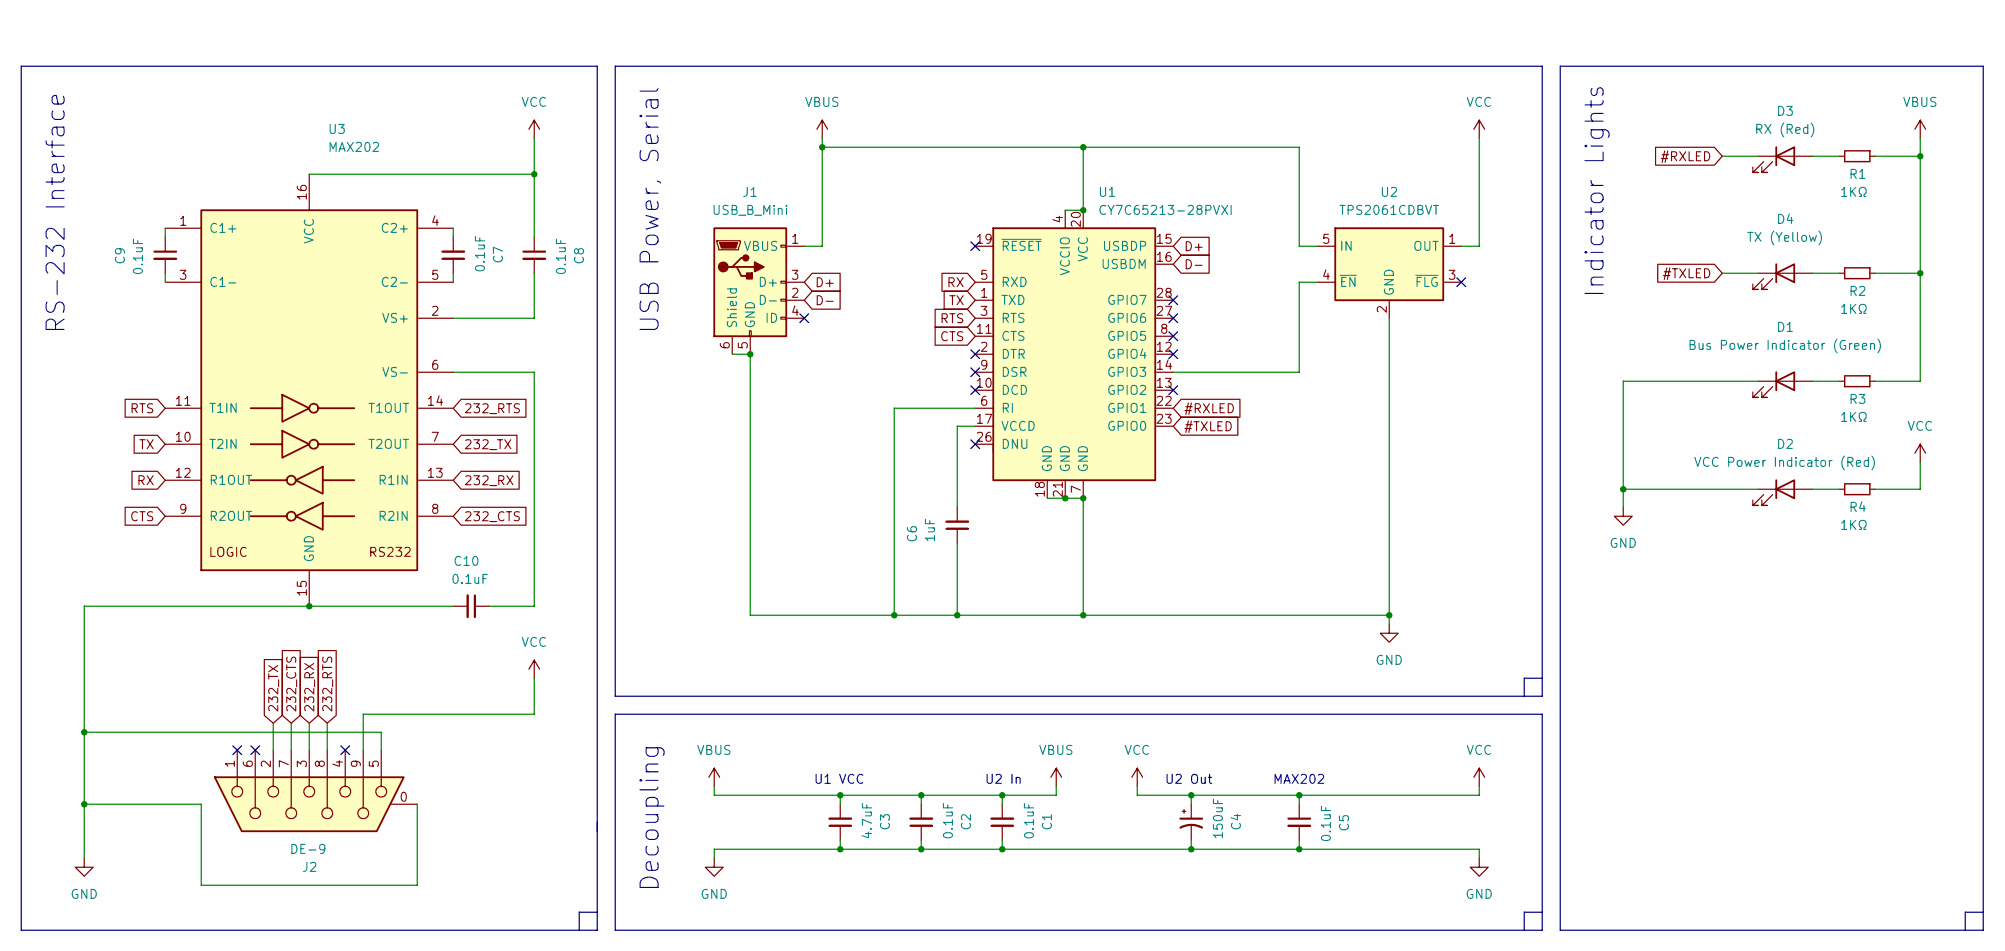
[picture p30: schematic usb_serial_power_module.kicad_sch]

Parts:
C1, C2, C5, C7, C8, C9, C10: 0.1uF; C_0805_2012Metric_Pad1.18x1.45mm_HandSolder
C3: 4.7uF; C_0805_2012Metric_Pad1.18x1.45mm_HandSolder
C4: 150uF; CP_EIA-6032-15_Kemet-U_Pad2.25x2.35mm_HandSolder
C6: 1uF; C_0805_2012Metric_Pad1.18x1.45mm_HandSolder
D1: Bus Power Indicator (Green); LED_0805_2012Metric_Pad1.15x1.40mm_HandSolder
D2: VCC Power Indicator (Red); LED_0805_2012Metric_Pad1.15x1.40mm_HandSolder
D3: RX (Red); LED_0805_2012Metric_Pad1.15x1.40mm_HandSolder
D4: TX (Yellow); LED_0805_2012Metric_Pad1.15x1.40mm_HandSolder
J1: USB_B_Mini; USB_Mini-B_Wuerth_65100516121_Horizontal
J2: DE-9; DSUB-9_Female_Horizontal_P2.77x2.84mm_EdgePinOffset7.70mm_H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
R1, R2, R3, R4: 1KΩ; R_0805_2012Metric_Pad1.20x1.40mm_HandSolder
U1: CY7C65213-28PVXI; SSOP-28_5.3x10.2mm_P0.65mm
U2: TPS2061CDBVT; SOT-23-5
U3: MAX202; SOIC-16_3.9x9.9mm_P1.27mm

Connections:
232_CTS: J2.7, U3.8 (R2IN)
232_RTS: J2.8, U3.14 (T1OUT)
232_RX: J2.3, U3.13 (R1IN)
232_TX: J2.2, U3.7 (T2OUT)
#RXLED: D3.1 (K), U1.22 (GPIO1)
#TXLED: D4.1 (K), U1.23 (GPIO0)
CTS: U1.11 (CTS), U3.9 (R2OUT)
D+: J1.3 (D+), U1.15 (USBDP)
D-: J1.2 (D-), U1.16 (USBDM)
GND: C1.1, C2.1, C3.1, C4.2, C5.2, C6.1, C10.2, D1.1 (K), D2.1 (K), J1.5 (GND), J1.6 (Shield), J2.0 (PAD), J2.5, U1.6 (RI), U1.7 (GND), U1.18 (GND), U1.21 (GND), U2.2 (GND), U3.15 (GND)
unnamed: C6.2, U1.17 (VCCD)
unnamed: C7.1, U3.5 (C2-)
unnamed: C7.2, U3.4 (C2+)
unnamed: C8.2, U3.2 (VS+)
unnamed: C9.1, U3.1 (C1+)
unnamed: C9.2, U3.3 (C1-)
unnamed: C10.1, U3.6 (VS-)
unnamed: D3.2 (A), R1.2
unnamed: D4.2 (A), R2.2
unnamed: D1.2 (A), R3.2
unnamed: D2.2 (A), R4.2
unnamed: U1.14 (GPIO3), U2.4 (~EN)
RTS: U1.3 (RTS), U3.11 (T1IN)
RX: U1.5 (RXD), U3.12 (R1OUT)
TX: U1.1 (TXD), U3.10 (T2IN)
VBUS: C1.2, C2.2, C3.2, J1.1 (VBUS), R1.1, R2.1, R3.1, U1.4 (VCCIO), U1.20 (VCC), U2.5 (IN)
VCC: C4.1, C5.1, C8.1, J2.9, R4.1, U2.1 (OUT), U3.16 (VCC)

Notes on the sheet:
Indicator Lights
Decoupling
RS-232 Interface
U1 VCC
U2 In
USB Power, Serial
MAX202
U2 Out

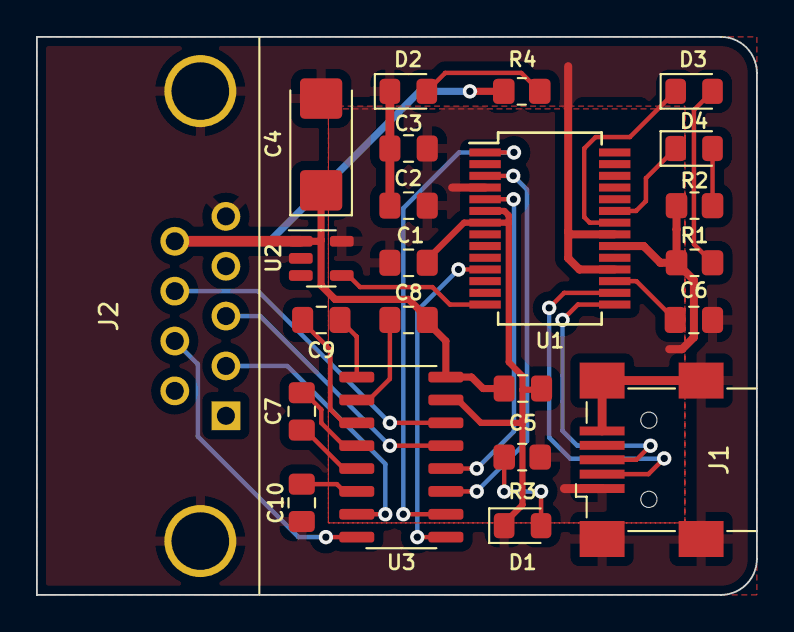
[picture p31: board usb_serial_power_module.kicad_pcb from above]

Board: 2 copper layers, 40.0 x 31.0 mm, 23 parts (0 on the bottom side), 27 nets.

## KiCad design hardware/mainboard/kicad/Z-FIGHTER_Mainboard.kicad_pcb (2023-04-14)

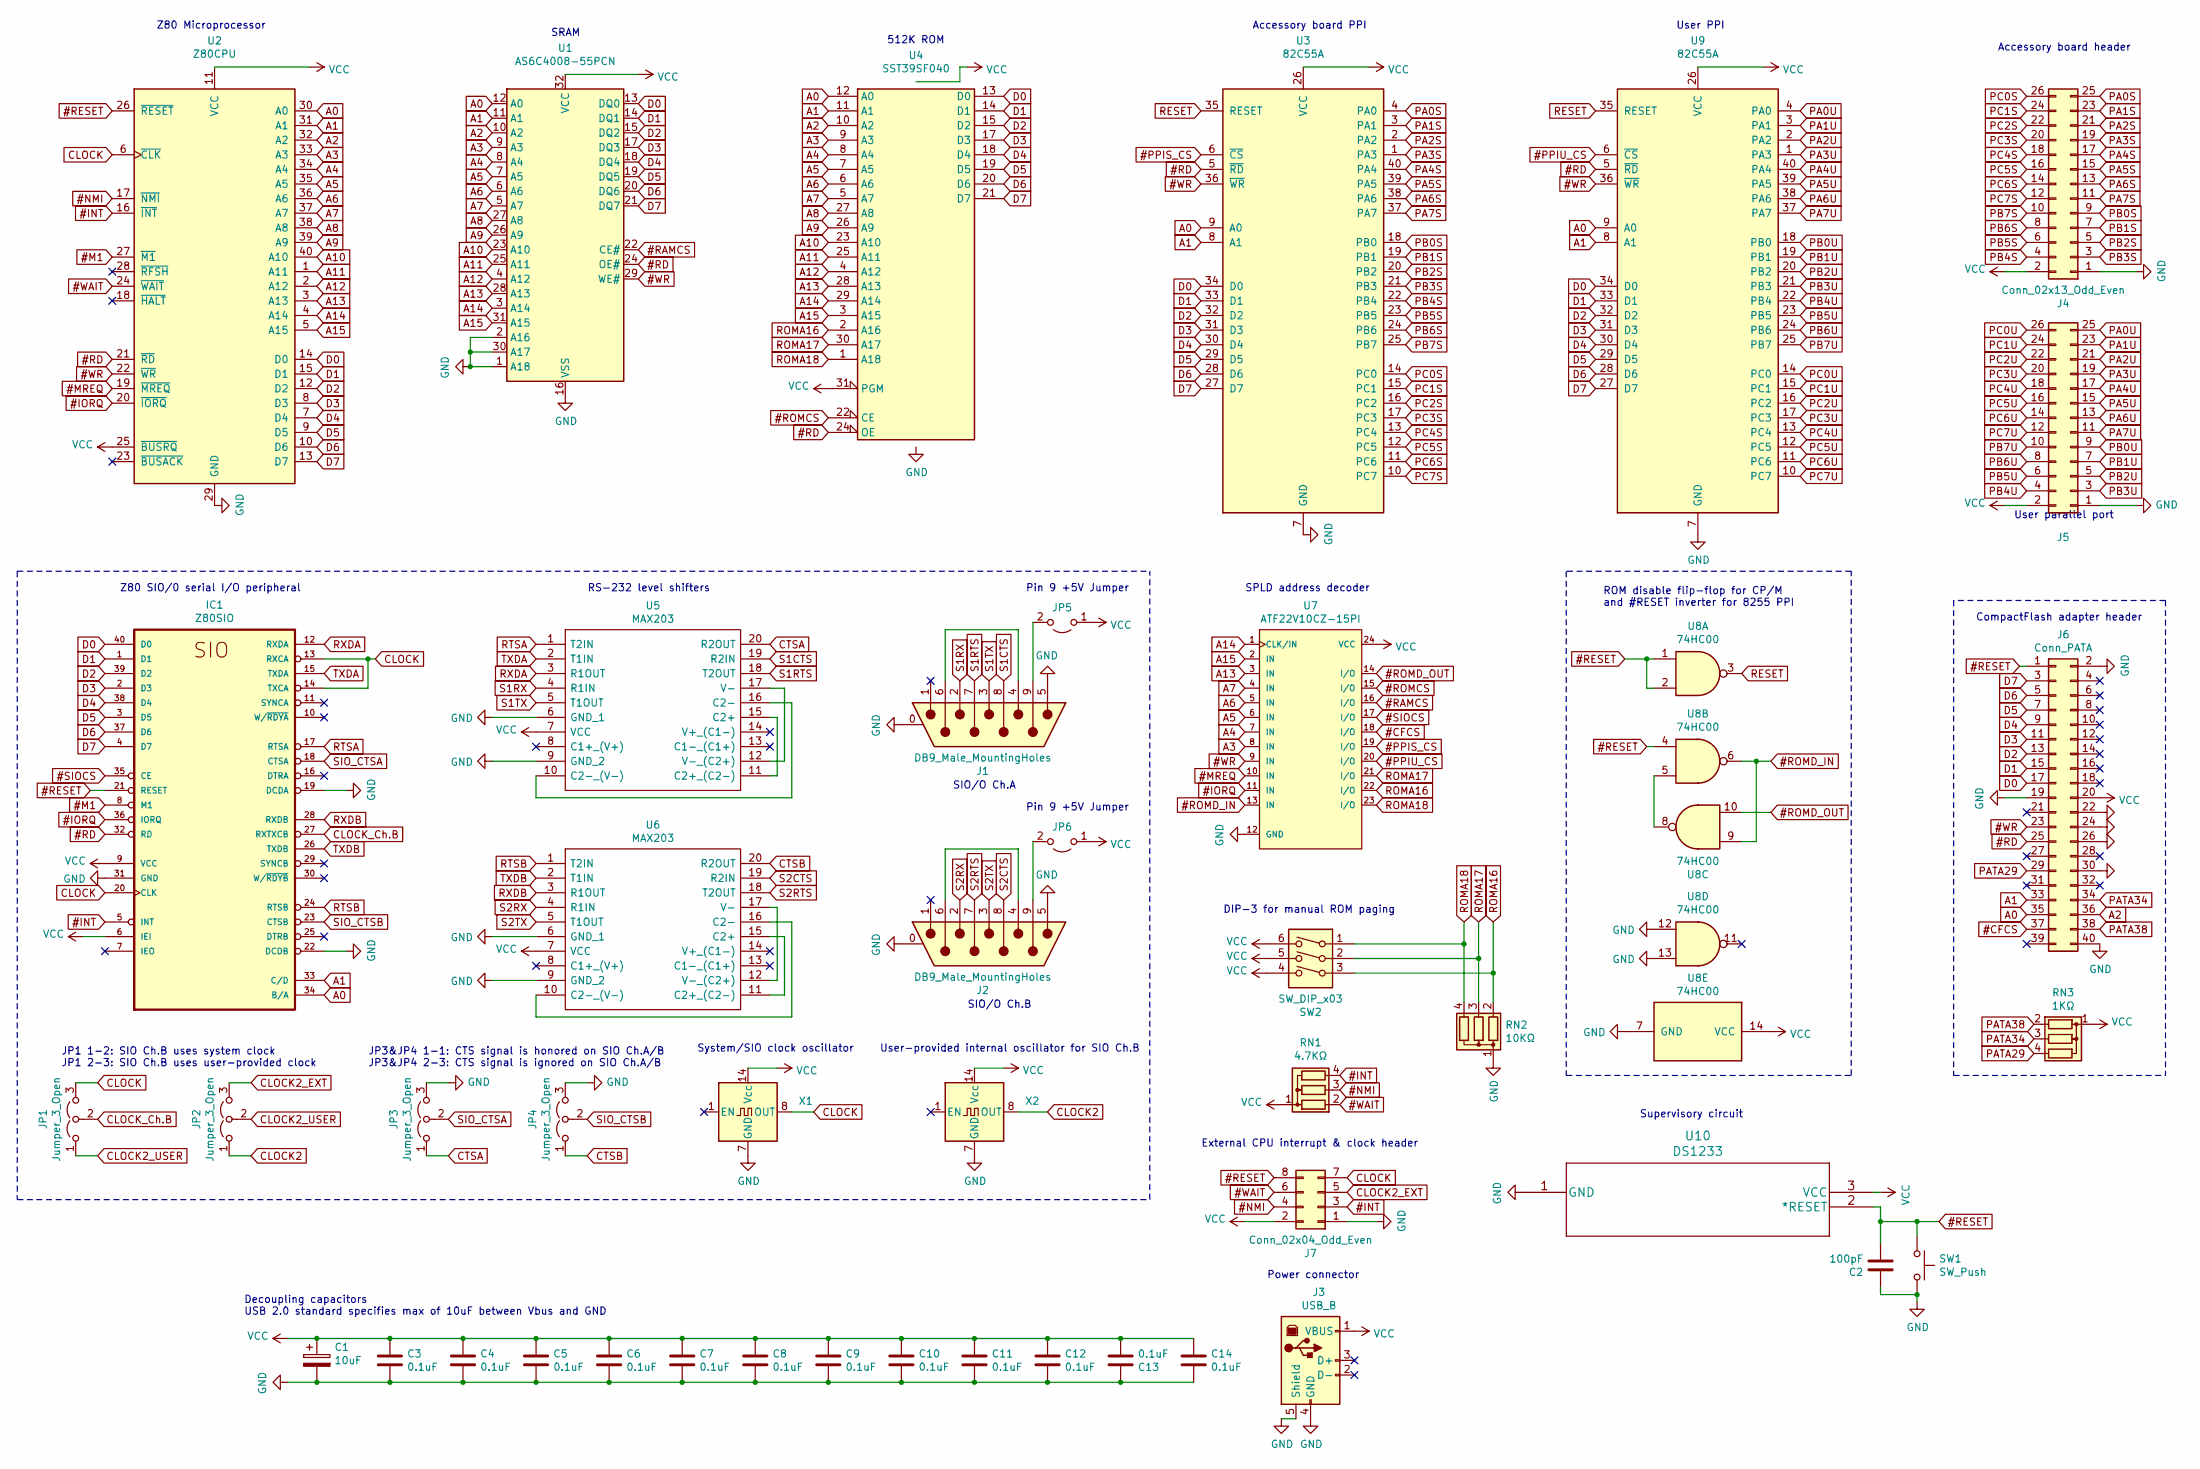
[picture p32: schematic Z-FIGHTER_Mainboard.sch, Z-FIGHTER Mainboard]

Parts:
C1: 10uF; CP_Radial_D5.0mm_P2.00mm
C2: 100pF; C_Disc_D7.5mm_W2.5mm_P5.00mm
C3, C4, C5, C6, C7, C8, C9, C10, C11, C12, C13, C14: 0.1uF; C_Disc_D7.5mm_W2.5mm_P5.00mm
IC1: Z80SIO; DIP-40_W15.24mm
J1, J2: DB9_Male_MountingHoles; DSUB-9_Male_Horizontal_P2.77x2.84mm_EdgePinOffset7.70mm_Hou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
J3: USB_B; USB_B_OST_USB-B1HSxx_Horizontal
J4: Conn_02x13_Odd_Even; IDC-Header_2x13_P2.54mm_Vertical
J5: Conn_Parallel_User; IDC-Header_2x13_P2.54mm_Horizontal
J6: Conn_PATA; IDC-Header_2x20_P2.54mm_Vertical
J7: Conn_02x04_Odd_Even; IDC-Header_2x04_P2.54mm_Horizontal
JP1, JP2, JP3, JP4: Jumper_3_Open; PinHeader_1x03_P2.54mm_Vertical
JP5, JP6: Jumper_2_Open; PinHeader_1x02_P2.54mm_Vertical
RN1: 4.7KΩ; R_Array_SIP4
RN2: 10KΩ; R_Array_SIP4
RN3: 1KΩ; R_Array_SIP4
SW1: SW_Push; SW_Tactile_SPST_Angled_PTS645Vx58-2LFS
SW2: SW_DIP_x03; SW_DIP_SPSTx03_Piano_10.8x9.18mm_W7.62mm_P2.54mm
U1: AS6C4008-55PCN; DIP-32_W15.24mm
U2: Z80CPU; DIP-40_W15.24mm
U3, U9: 82C55A; DIP-40_W15.24mm
U4: SST39SF040; DIP-32_W15.24mm
U5, U6: MAX203; DIP-20_W7.62mm
U7: ATF22V10CZ-15PI; DIP-24_W7.62mm
U8: 74HC00
U10: DS1233; TO-92_Inline_Wide
X1: Z80/SIO Ch.A Clock; Oscillator_DIP-14_LargePads
X2: SIO Ch.B Clock; Oscillator_DIP-14_LargePads

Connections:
#CFCS: J6.37, U7.18 (I/O)
#INT: IC1.5 (INT), J7.3, RN1.4 (R3), U2.16 (~INT~)
#IORQ: IC1.36 (IORQ), U2.20 (~IORQ~), U7.11 (IN)
#M1: IC1.8 (M1), U2.27 (~M1~)
#MREQ: U2.19 (~MREQ~), U7.10 (IN)
#NMI: J7.4, RN1.3 (R2), U2.17 (~NMI~)
#PPIS_CS: U3.6 (~CS~), U7.19 (I/O)
#PPIU_CS: U7.20 (I/O), U9.6 (~CS~)
#RAMCS: U1.22 (CE#), U7.16 (I/O)
#RD: IC1.32 (RD), J6.25, U1.24 (OE#), U2.21 (~RD~), U3.5 (~RD~), U4.24 (OE), U9.5 (~RD~)
#RESET: C2.2, IC1.21 (RESET), J6.1, J7.8, SW1.1, U2.26 (~RESET~), U8.1, U8.2, U8.4, U10.2 (*RESET)
#ROMCS: U4.22 (CE), U7.15 (I/O)
#ROMD_IN: U7.13 (IN), U8.6, U8.9
#ROMD_OUT: U7.14 (I/O), U8.10
#SIOCS: IC1.35 (CE), U7.17 (I/O)
#WAIT: J7.6, RN1.2 (R1), U2.24 (~WAIT~)
#WR: J6.23, U1.29 (WE#), U2.22 (~WR~), U3.36 (~WR~), U7.9 (IN), U9.36 (~WR~)
A0: IC1.34 (B/A), J6.35, U1.12 (A0), U2.30 (A0), U3.9 (A0), U4.12 (A0), U9.9 (A0)
A1: IC1.33 (C/D), J6.33, U1.11 (A1), U2.31 (A1), U3.8 (A1), U4.11 (A1), U9.8 (A1)
A2: J6.36, U1.10 (A2), U2.32 (A2), U4.10 (A2)
A3: U1.9 (A3), U2.33 (A3), U4.9 (A3), U7.8 (IN)
A4: U1.8 (A4), U2.34 (A4), U4.8 (A4), U7.7 (IN)
A5: U1.7 (A5), U2.35 (A5), U4.7 (A5), U7.6 (IN)
A6: U1.6 (A6), U2.36 (A6), U4.6 (A6), U7.5 (IN)
A7: U1.5 (A7), U2.37 (A7), U4.5 (A7), U7.4 (IN)
A8: U1.27 (A8), U2.38 (A8), U4.27 (A8)
A9: U1.26 (A9), U2.39 (A9), U4.26 (A9)
A10: U1.23 (A10), U2.40 (A10), U4.23 (A10)
A11: U1.25 (A11), U2.1 (A11), U4.25 (A11)
A12: U1.4 (A12), U2.2 (A12), U4.4 (A12)
A13: U1.28 (A13), U2.3 (A13), U4.28 (A13), U7.3 (IN)
A14: U1.3 (A14), U2.4 (A14), U4.29 (A14), U7.1 (CLK/IN)
A15: U1.31 (A15), U2.5 (A15), U4.3 (A15), U7.2 (IN)
CLOCK: IC1.13 (RXCA), IC1.14 (TXCA), IC1.20 (CLK), J7.7, JP1.3 (B), U2.6 (~CLK~), X1.8 (OUT)
CLOCK2: JP2.1 (A), X2.8 (OUT)
CLOCK2_EXT: J7.5, JP2.3 (B)
CLOCK2_USER: JP1.1 (A), JP2.2 (C)
CLOCK_Ch.B: IC1.27 (RXTXCB), JP1.2 (C)
CTSA: JP3.1 (A), U5.20 (R2OUT)
CTSB: JP4.1 (A), U6.20 (R2OUT)
D0: IC1.40 (D0), J6.17, U1.13 (DQ0), U2.14 (D0), U3.34 (D0), U4.13 (D0), U9.34 (D0)
D1: IC1.1 (D1), J6.15, U1.14 (DQ1), U2.15 (D1), U3.33 (D1), U4.14 (D1), U9.33 (D1)
D2: IC1.39 (D2), J6.13, U1.15 (DQ2), U2.12 (D2), U3.32 (D2), U4.15 (D2), U9.32 (D2)
D3: IC1.2 (D3), J6.11, U1.17 (DQ3), U2.8 (D3), U3.31 (D3), U4.17 (D3), U9.31 (D3)
D4: IC1.38 (D4), J6.9, U1.18 (DQ4), U2.7 (D4), U3.30 (D4), U4.18 (D4), U9.30 (D4)
D5: IC1.3 (D5), J6.7, U1.19 (DQ5), U2.9 (D5), U3.29 (D5), U4.19 (D5), U9.29 (D5)
D6: IC1.37 (D6), J6.5, U1.20 (DQ6), U2.10 (D6), U3.28 (D6), U4.20 (D6), U9.28 (D6)
D7: IC1.4 (D7), J6.3, U1.21 (DQ7), U2.13 (D7), U3.27 (D7), U4.21 (D7), U9.27 (D7)
GND: C1.2, C2.1, C3.2, C4.2, C5.2, C6.2, C7.2, C8.2, C9.2, C10.2, C11.2, C12.2, C13.1, C14.2, IC1.19 (DCDA), IC1.22 (DCDB), IC1.31 (GND), J1.0 (PAD), J1.5, J2.0 (PAD), J2.5, J3.4 (GND), J3.5 (Shield), J4.1, J5.1, J6.2, J6.19, J6.22, J6.24, J6.26, J6.30, J6.40, J7.1, JP3.3 (B), JP4.3 (B), RN2.1 (common), SW1.2, U1.1 (A18), U1.2 (A16), U1.16 (VSS), U1.30 (A17), U2.29 (GND), U3.7 (GND), U4.16 (GND), U5.6 (GND_1), U5.9 (GND_2), U6.6 (GND_1), U6.9 (GND_2), U7.12 (GND), U8.7 (GND), U8.12, U8.13, U9.7 (GND), U10.1 (GND), X1.7 (GND), X2.7 (GND)
HALT: U2.18 (~HALT~)
unnamed: J1.4, J1.6
unnamed: J1.9, JP5.2 (B)
unnamed: J2.4, J2.6
unnamed: J2.9, JP6.2 (B)
unnamed: U5.10 (C2-_(V-)), U5.16 (C2-)
unnamed: U5.11 (C2+_(C2-)), U5.15 (C2+)
unnamed: U5.12 (V-_(C2+)), U5.17 (V-)
unnamed: U6.10 (C2-_(V-)), U6.16 (C2-)
unnamed: U6.11 (C2+_(C2-)), U6.15 (C2+)
unnamed: U6.12 (V-_(C2+)), U6.17 (V-)
unnamed: U8.5, U8.8
PA0S: J4.25, U3.4 (PA0)
PA0U: J5.25, U9.4 (PA0)
PA1S: J4.23, U3.3 (PA1)
PA1U: J5.23, U9.3 (PA1)
PA2S: J4.21, U3.2 (PA2)
PA2U: J5.21, U9.2 (PA2)
PA3S: J4.19, U3.1 (PA3)
PA3U: J5.19, U9.1 (PA3)
PA4S: J4.17, U3.40 (PA4)
PA4U: J5.17, U9.40 (PA4)
PA5S: J4.15, U3.39 (PA5)
PA5U: J5.15, U9.39 (PA5)
PA6S: J4.13, U3.38 (PA6)
PA6U: J5.13, U9.38 (PA6)
PA7S: J4.11, U3.37 (PA7)
PA7U: J5.11, U9.37 (PA7)
PATA29: J6.29, RN3.4 (R3)
PATA34: J6.34, RN3.3 (R2)
PATA38: J6.38, RN3.2 (R1)
PB0S: J4.9, U3.18 (PB0)
PB0U: J5.9, U9.18 (PB0)
PB1S: J4.7, U3.19 (PB1)
PB1U: J5.7, U9.19 (PB1)
PB2S: J4.5, U3.20 (PB2)
PB2U: J5.5, U9.20 (PB2)
PB3S: J4.3, U3.21 (PB3)
PB3U: J5.3, U9.21 (PB3)
PB4S: J4.4, U3.22 (PB4)
PB4U: J5.4, U9.22 (PB4)
PB5S: J4.6, U3.23 (PB5)
PB5U: J5.6, U9.23 (PB5)
PB6S: J4.8, U3.24 (PB6)
PB6U: J5.8, U9.24 (PB6)
PB7S: J4.10, U3.25 (PB7)
PB7U: J5.10, U9.25 (PB7)
PC0S: J4.26, U3.14 (PC0)
PC0U: J5.26, U9.14 (PC0)
PC1S: J4.24, U3.15 (PC1)
PC1U: J5.24, U9.15 (PC1)
PC2S: J4.22, U3.16 (PC2)
PC2U: J5.22, U9.16 (PC2)
PC3S: J4.20, U3.17 (PC3)
PC3U: J5.20, U9.17 (PC3)
PC4S: J4.18, U3.13 (PC4)
PC4U: J5.18, U9.13 (PC4)
PC5S: J4.16, U3.12 (PC5)
PC5U: J5.16, U9.12 (PC5)
PC6S: J4.14, U3.11 (PC6)
PC6U: J5.14, U9.11 (PC6)
PC7S: J4.12, U3.10 (PC7)
PC7U: J5.12, U9.10 (PC7)
RESET: U3.35 (RESET), U8.3, U9.35 (RESET)
ROMA16: RN2.2 (R1), SW2.3, U4.2 (A16), U7.22 (I/O)
ROMA17: RN2.3 (R2), SW2.2, U4.30 (A17), U7.21 (I/O)
ROMA18: RN2.4 (R3), SW2.1, U4.1 (A18), U7.23 (I/O)
RTSA: IC1.17 (RTSA), U5.1 (T2IN)
RTSB: IC1.24 (RTSB), U6.1 (T2IN)
RXDA: IC1.12 (RXDA), U5.3 (R1OUT)
RXDB: IC1.28 (RXDB), U6.3 (R1OUT)
S1CTS: J1.8, U5.19 (R2IN)
S1RTS: J1.7, U5.18 (T2OUT)
S1RX: J1.2, U5.4 (R1IN)
S1TX: J1.3, U5.5 (T1OUT)
S2CTS: J2.8, U6.19 (R2IN)
S2RTS: J2.7, U6.18 (T2OUT)
S2RX: J2.2, U6.4 (R1IN)
S2TX: J2.3, U6.5 (T1OUT)
SIO_CTSA: IC1.18 (CTSA), JP3.2 (C)
SIO_CTSB: IC1.23 (CTSB), JP4.2 (C)
TXDA: IC1.15 (TXDA), U5.2 (T1IN)
TXDB: IC1.26 (TXDB), U6.2 (T1IN)
VCC: C1.1, C3.1, C4.1, C5.1, C6.1, C7.1, C8.1, C9.1, C10.1, C11.1, C12.1, C13.2, C14.1, IC1.6 (IEI), IC1.9 (VCC), J3.1 (VBUS), J4.2, J5.2, J6.20, J7.2, JP5.1 (A), JP6.1 (A), RN1.1 (common), RN3.1 (common), SW2.4, SW2.5, SW2.6, U1.32 (VCC), U2.11 (VCC), U2.25 (~BUSRQ~), U3.26 (VCC), U4.31 (PGM), U4.32 (VCC), U5.7 (VCC), U6.7 (VCC), U7.24 (VCC), U8.14 (VCC), U9.26 (VCC), U10.3 (VCC), X1.14 (Vcc), X2.14 (Vcc)

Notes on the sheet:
Decoupling capacitors USB 2.0 standard specifies max of 10uF between Vbus and GND
System/SIO clock oscillator
Z80 SIO/0 serial I/O peripheral
512K ROM
Accessory board PPI
User PPI
Accessory board header
User parallel port
JP3&JP4 1-1: CTS signal is honored on SIO Ch.A/B JP3&JP4 2-3: CTS signal is ignored on SIO Ch.A/B
ROM disable flip-flop for CP/M and #RESET inverter for 8255 PPI
RS-232 level shifters
SIO/O Ch.A
SIO/O Ch.B
User-provided internal oscillator for SIO Ch.B
Power connector
CompactFlash adapter header
DIP-3 for manual ROM paging
SPLD address decoder
Supervisory circuit
External CPU interrupt & clock header
Pin 9 +5V Jumper
Z80 Microprocessor
SRAM
JP1 1-2: SIO Ch.B uses system clock JP1 2-3: SIO Ch.B uses user-provided clock

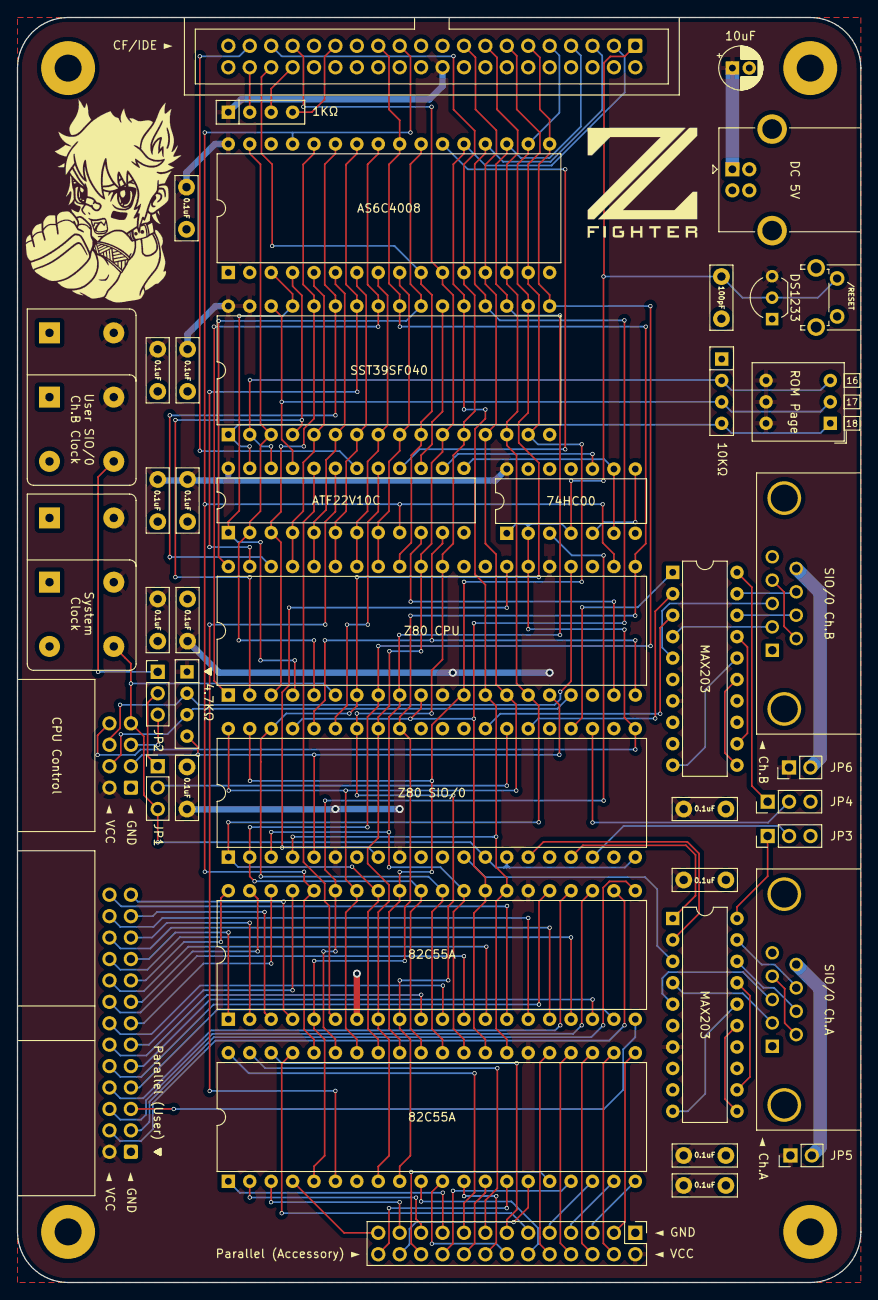
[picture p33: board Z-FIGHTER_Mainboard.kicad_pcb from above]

Board: 2 copper layers, 100.0 x 150.0 mm, 49 parts (0 on the bottom side), 132 nets.

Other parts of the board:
Mount1, Mount2, Mount3, Mount4: MountingHole_3.2mm_M3_Pad

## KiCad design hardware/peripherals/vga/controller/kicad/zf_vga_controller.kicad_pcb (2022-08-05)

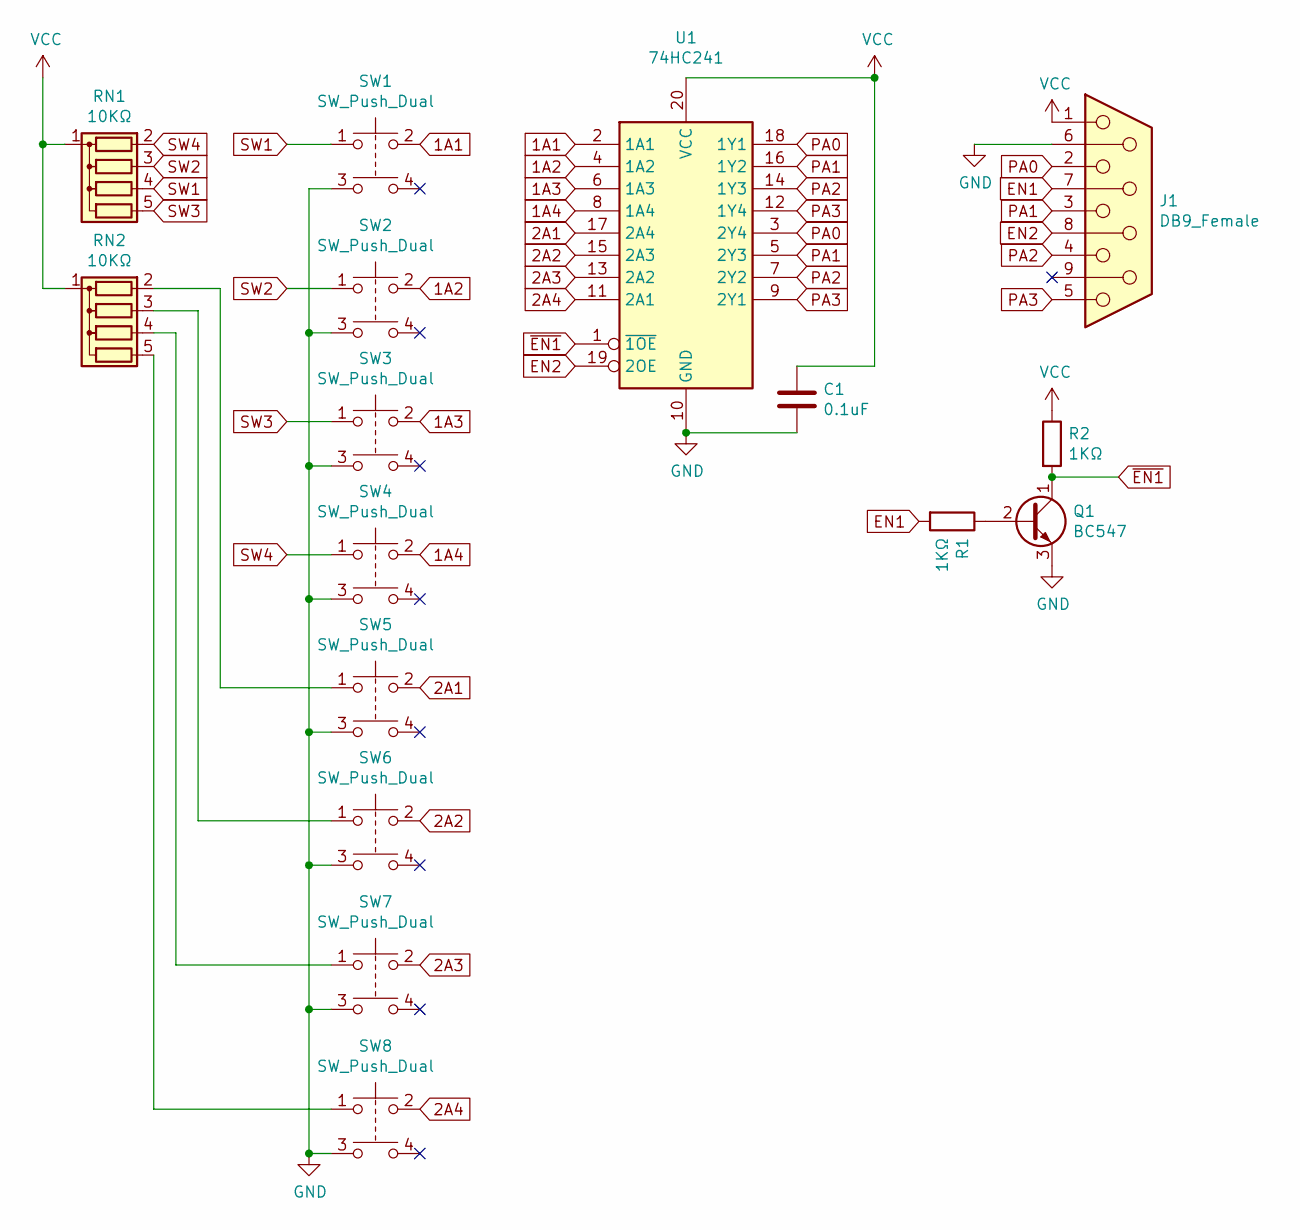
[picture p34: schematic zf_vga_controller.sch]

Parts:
C1: 0.1uF; C_Disc_D7.5mm_W2.5mm_P5.00mm
J1: DB9_Female; DSUB-9_Female_Horizontal_P2.77x2.84mm_EdgePinOffset7.70mm_H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
Q1: BC547; TO-92_Inline_Wide
R1, R2: 1KΩ; R_Axial_DIN0207_L6.3mm_D2.5mm_P7.62mm_Horizontal
RN1, RN2: 10KΩ; R_Array_SIP5
SW1, SW2, SW3, SW4, SW5, SW6, SW7, SW8: SW_Push_Dual; SW_B3F-4050
U1: 74HC241; DIP-20_W7.62mm

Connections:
1A1: SW1.2, U1.2 (1A1)
1A2: SW2.2, U1.4 (1A2)
1A3: SW3.2, U1.6 (1A3)
1A4: SW4.2, U1.8 (1A4)
2A1: SW5.2, U1.17 (2A4)
2A2: SW6.2, U1.15 (2A3)
2A3: SW7.2, U1.13 (2A2)
2A4: SW8.2, U1.11 (2A1)
EN1: J1.7, R1.2
EN2: J1.8, U1.19 (2OE)
GND: C1.2, J1.6, Q1.3 (E), SW1.3, SW2.3, SW3.3, SW4.3, SW5.3, SW6.3, SW7.3, SW8.3, U1.10 (GND)
unnamed: Q1.2 (B), R1.1
unnamed: RN2.2 (R1), SW5.1
unnamed: RN2.3 (R2), SW6.1
unnamed: RN2.4 (R3), SW7.1
unnamed: RN2.5 (R4), SW8.1
PA0: J1.2, U1.3 (2Y4), U1.18 (1Y1)
PA1: J1.3, U1.5 (2Y3), U1.16 (1Y2)
PA2: J1.4, U1.7 (2Y2), U1.14 (1Y3)
PA3: J1.5, U1.9 (2Y1), U1.12 (1Y4)
SW1: RN1.4 (R3), SW1.1
SW2: RN1.3 (R2), SW2.1
SW3: RN1.5 (R4), SW3.1
SW4: RN1.2 (R1), SW4.1
VCC: C1.1, J1.1, R2.1, RN1.1 (common), RN2.1 (common), U1.20 (VCC)
~EN1: Q1.1 (C), R2.2, U1.1 (~1OE)

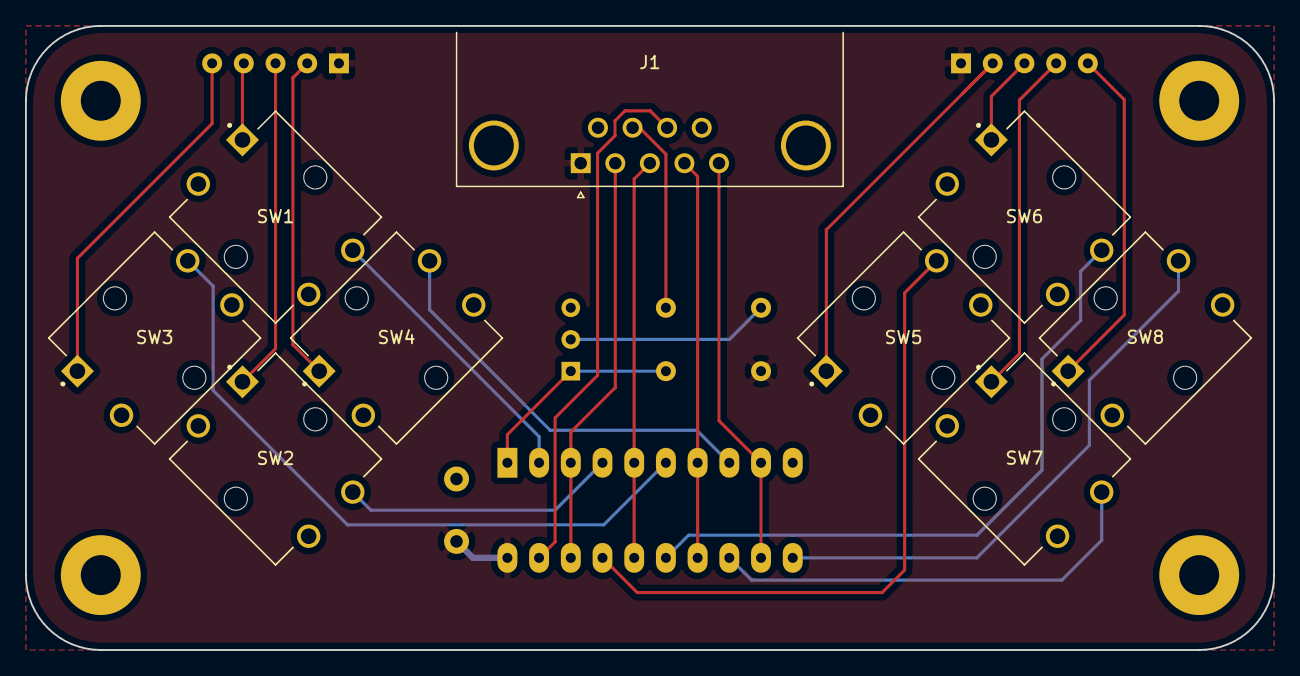
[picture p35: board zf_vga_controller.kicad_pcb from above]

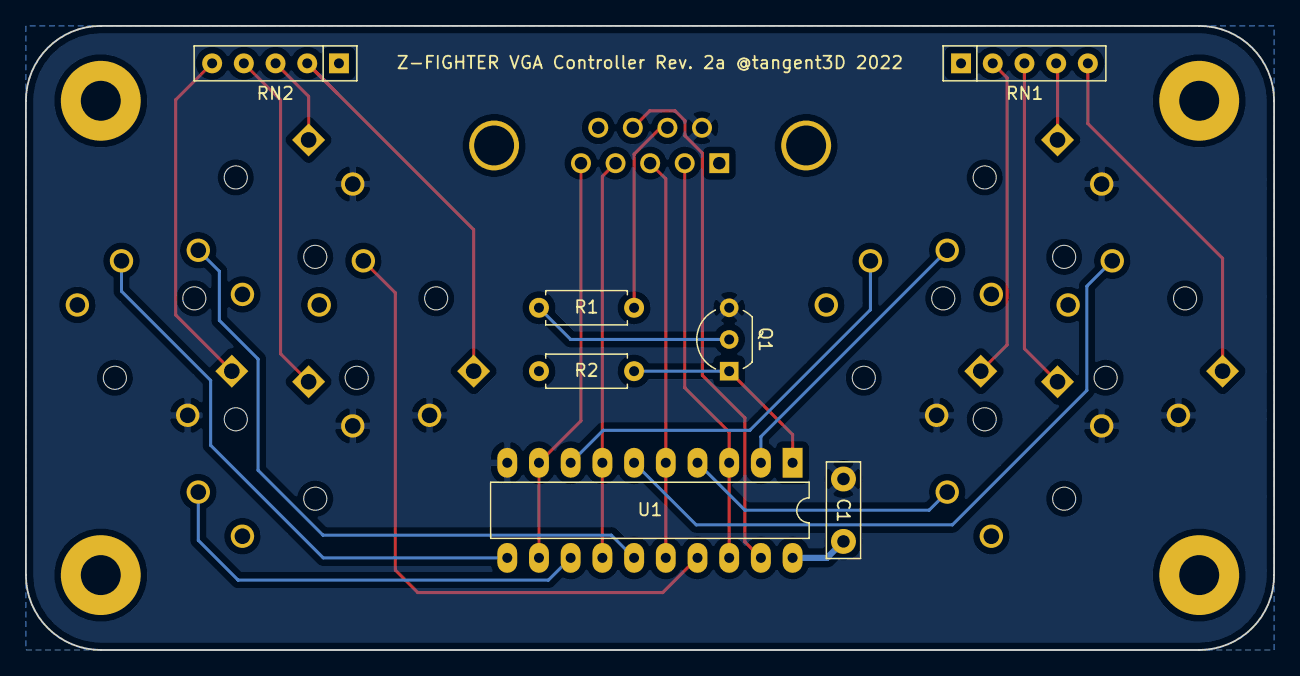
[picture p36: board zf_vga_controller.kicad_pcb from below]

Board: 2 copper layers, 100.0 x 50.0 mm, 20 parts (7 on the bottom side), 26 nets.

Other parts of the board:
Mount1, Mount1#2, Mount1#3, Mount1#4: MountingHole_3.2mm_M3_Pad

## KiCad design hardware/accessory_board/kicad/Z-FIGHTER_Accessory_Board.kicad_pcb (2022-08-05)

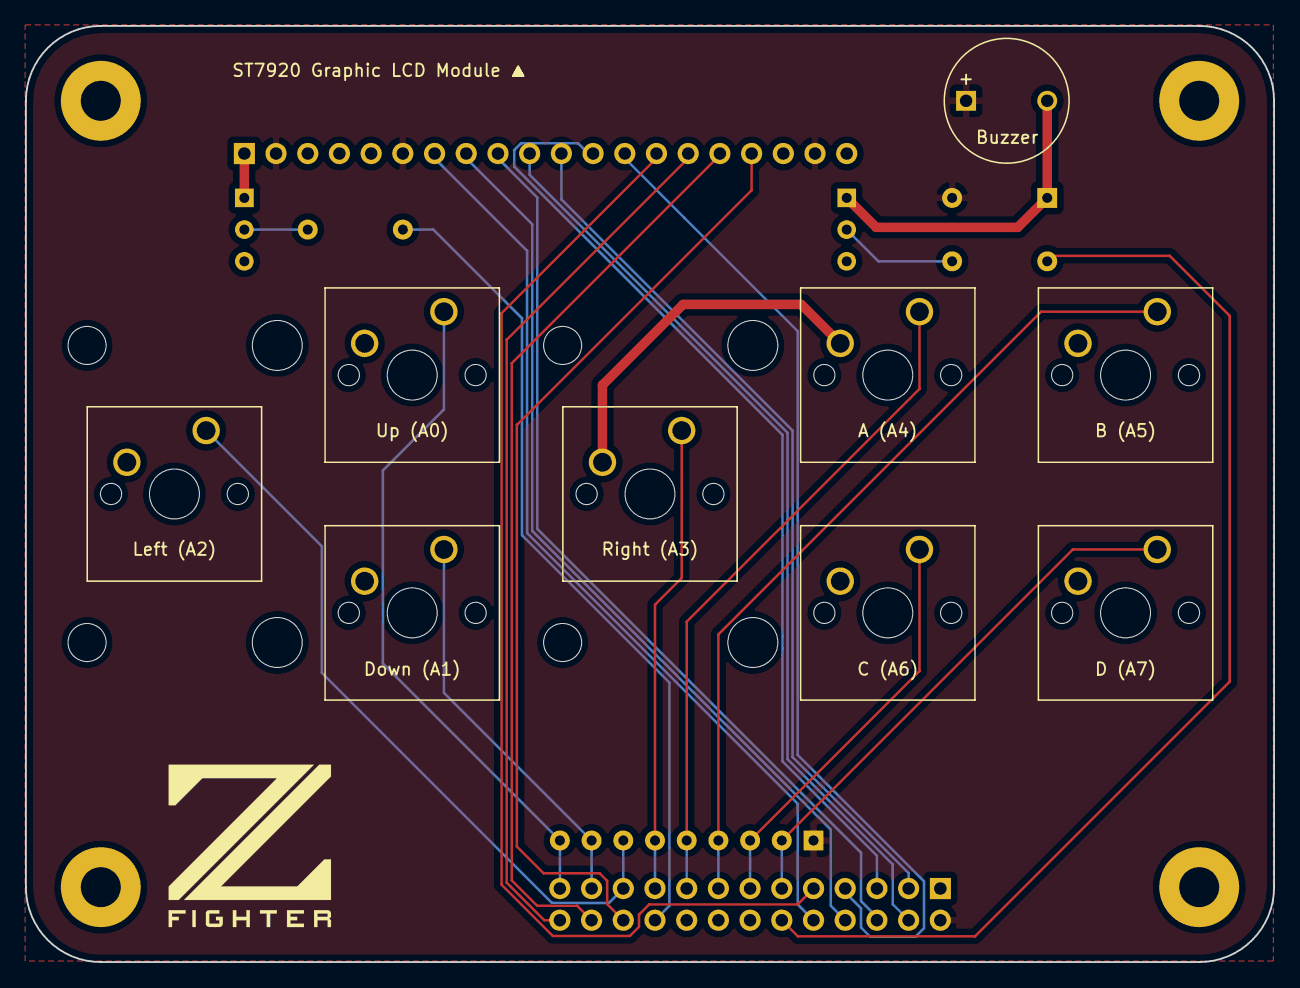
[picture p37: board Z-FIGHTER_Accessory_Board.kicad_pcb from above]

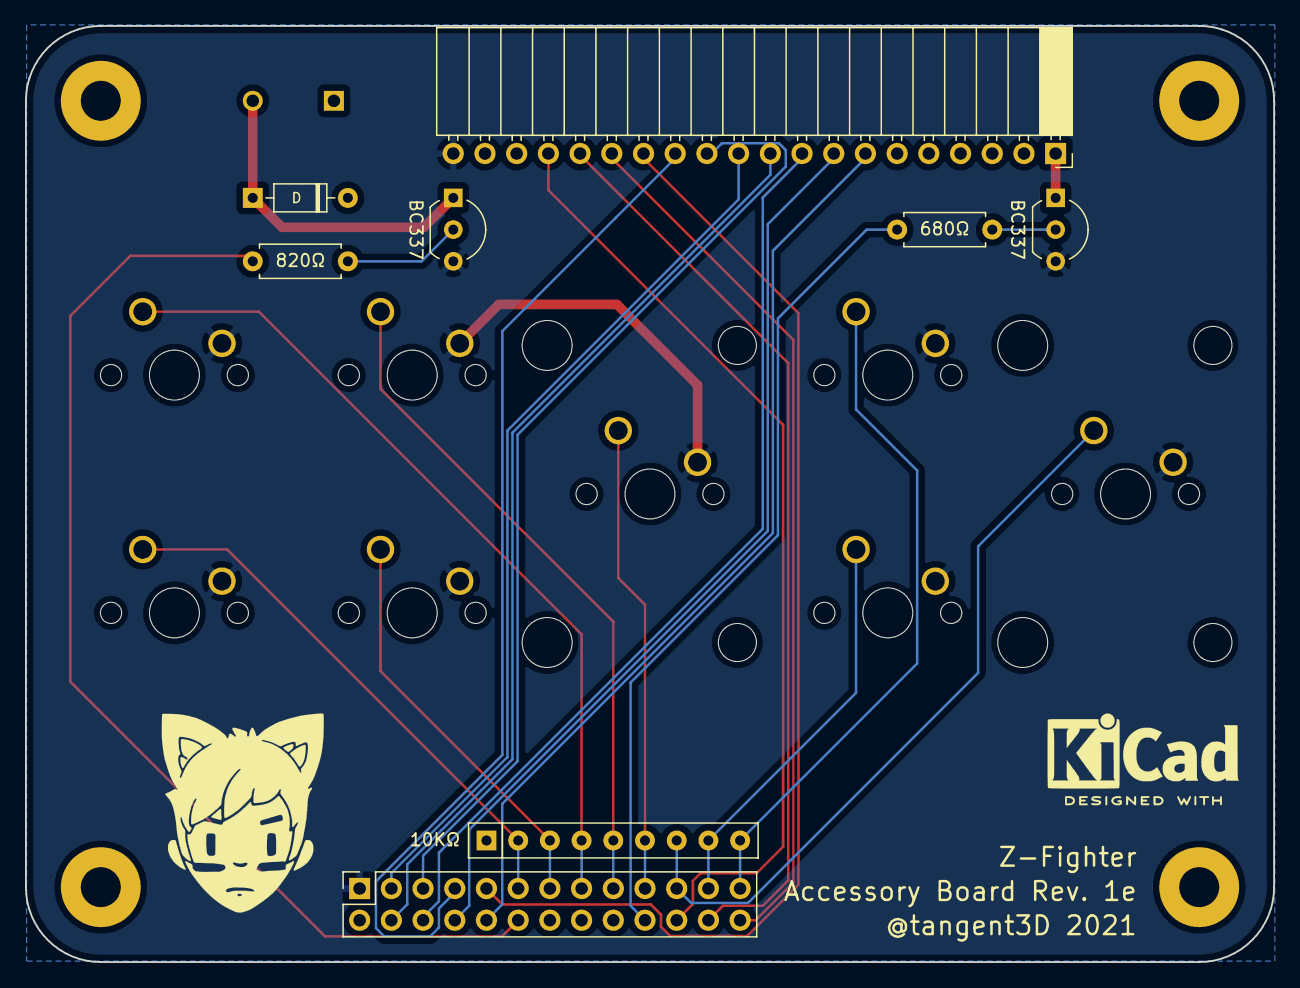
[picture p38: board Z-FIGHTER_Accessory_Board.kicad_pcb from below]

Board: 2 copper layers, 100.0 x 75.0 mm, 21 parts (8 on the bottom side), 27 nets.

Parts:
BZ1: Buzzer; MagneticBuzzer_ProSignal_ABT-410-RC
D2: IN5817; D_DO-35_SOD27_P7.62mm_Horizontal
J7: ST7920 Graphic LCD; PinSocket_1x20_P2.54mm_Horizontal
J9: Conn_02x13_Odd_Even; PinSocket_2x13_P2.54mm_Vertical
Mount1, Mount2, Mount3, Mount4: MountingHole_3.2mm_M3_Pad
Q1, Q2: BC337; TO-92_Inline_Wide
RB1: 680Ω; R_Axial_DIN0207_L6.3mm_D2.5mm_P7.62mm_Horizontal
RB2: 820Ω; R_Axial_DIN0207_L6.3mm_D2.5mm_P7.62mm_Horizontal
RN4: 10KΩ; R_Array_SIP9
SW1: Up (A0); SW_Cherry_MX_1.00u_PCB
SW2: Down (A1); SW_Cherry_MX_1.00u_PCB
SW3: Left (A2); SW_Cherry_MX_2.00u_Vertical_PCB
SW4: Right (A3); SW_Cherry_MX_2.00u_Vertical_PCB
SW5: A (A4); SW_Cherry_MX_1.00u_PCB
SW6: B (A5); SW_Cherry_MX_1.00u_PCB
SW7: C (A6); SW_Cherry_MX_1.00u_PCB
SW8: D (A7); SW_Cherry_MX_1.00u_PCB

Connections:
BLK: J7.1, Q1.1
GND: J7.20, J9.1, Q1.3, Q2.3, SW1.2, SW2.2, SW3.2, SW4.2, SW5.2, SW6.2, SW7.2, SW8.2
unnamed: BZ1.2, D2.1, Q2.1
unnamed: Q1.2, RB1.1
unnamed: Q2.2, RB2.1
PA0S: J9.25, RN4.9, SW1.1
PA1S: J9.23, RN4.8, SW2.1
PA2S: J9.21, RN4.7, SW3.1
PA3S: J9.19, RN4.6, SW4.1
PA4S: J9.17, RN4.5, SW5.1
PA5S: J9.15, RN4.4, SW6.1
PA6S: J9.13, RN4.3, SW7.1
PA7S: J9.11, RN4.2, SW8.1
PB0S: J7.14, J9.9
PB1S: J7.13, J9.7
PB2S: J7.12, J9.5
PB3S: J7.11, J9.3
PB4S: J7.10, J9.4
PB5S: J7.9, J9.6
PB6S: J7.8, J9.8
PB7S: J7.7, J9.10
PC0S: J7.15, J9.26
PC1S: J7.16, J9.24
PC2S: J7.17, J9.22
PC3S: J9.20, RB1.2
PC7S: J9.12, RB2.2
VCC: BZ1.1, D2.2, J7.2, J7.6, J7.19, J9.2, RN4.1

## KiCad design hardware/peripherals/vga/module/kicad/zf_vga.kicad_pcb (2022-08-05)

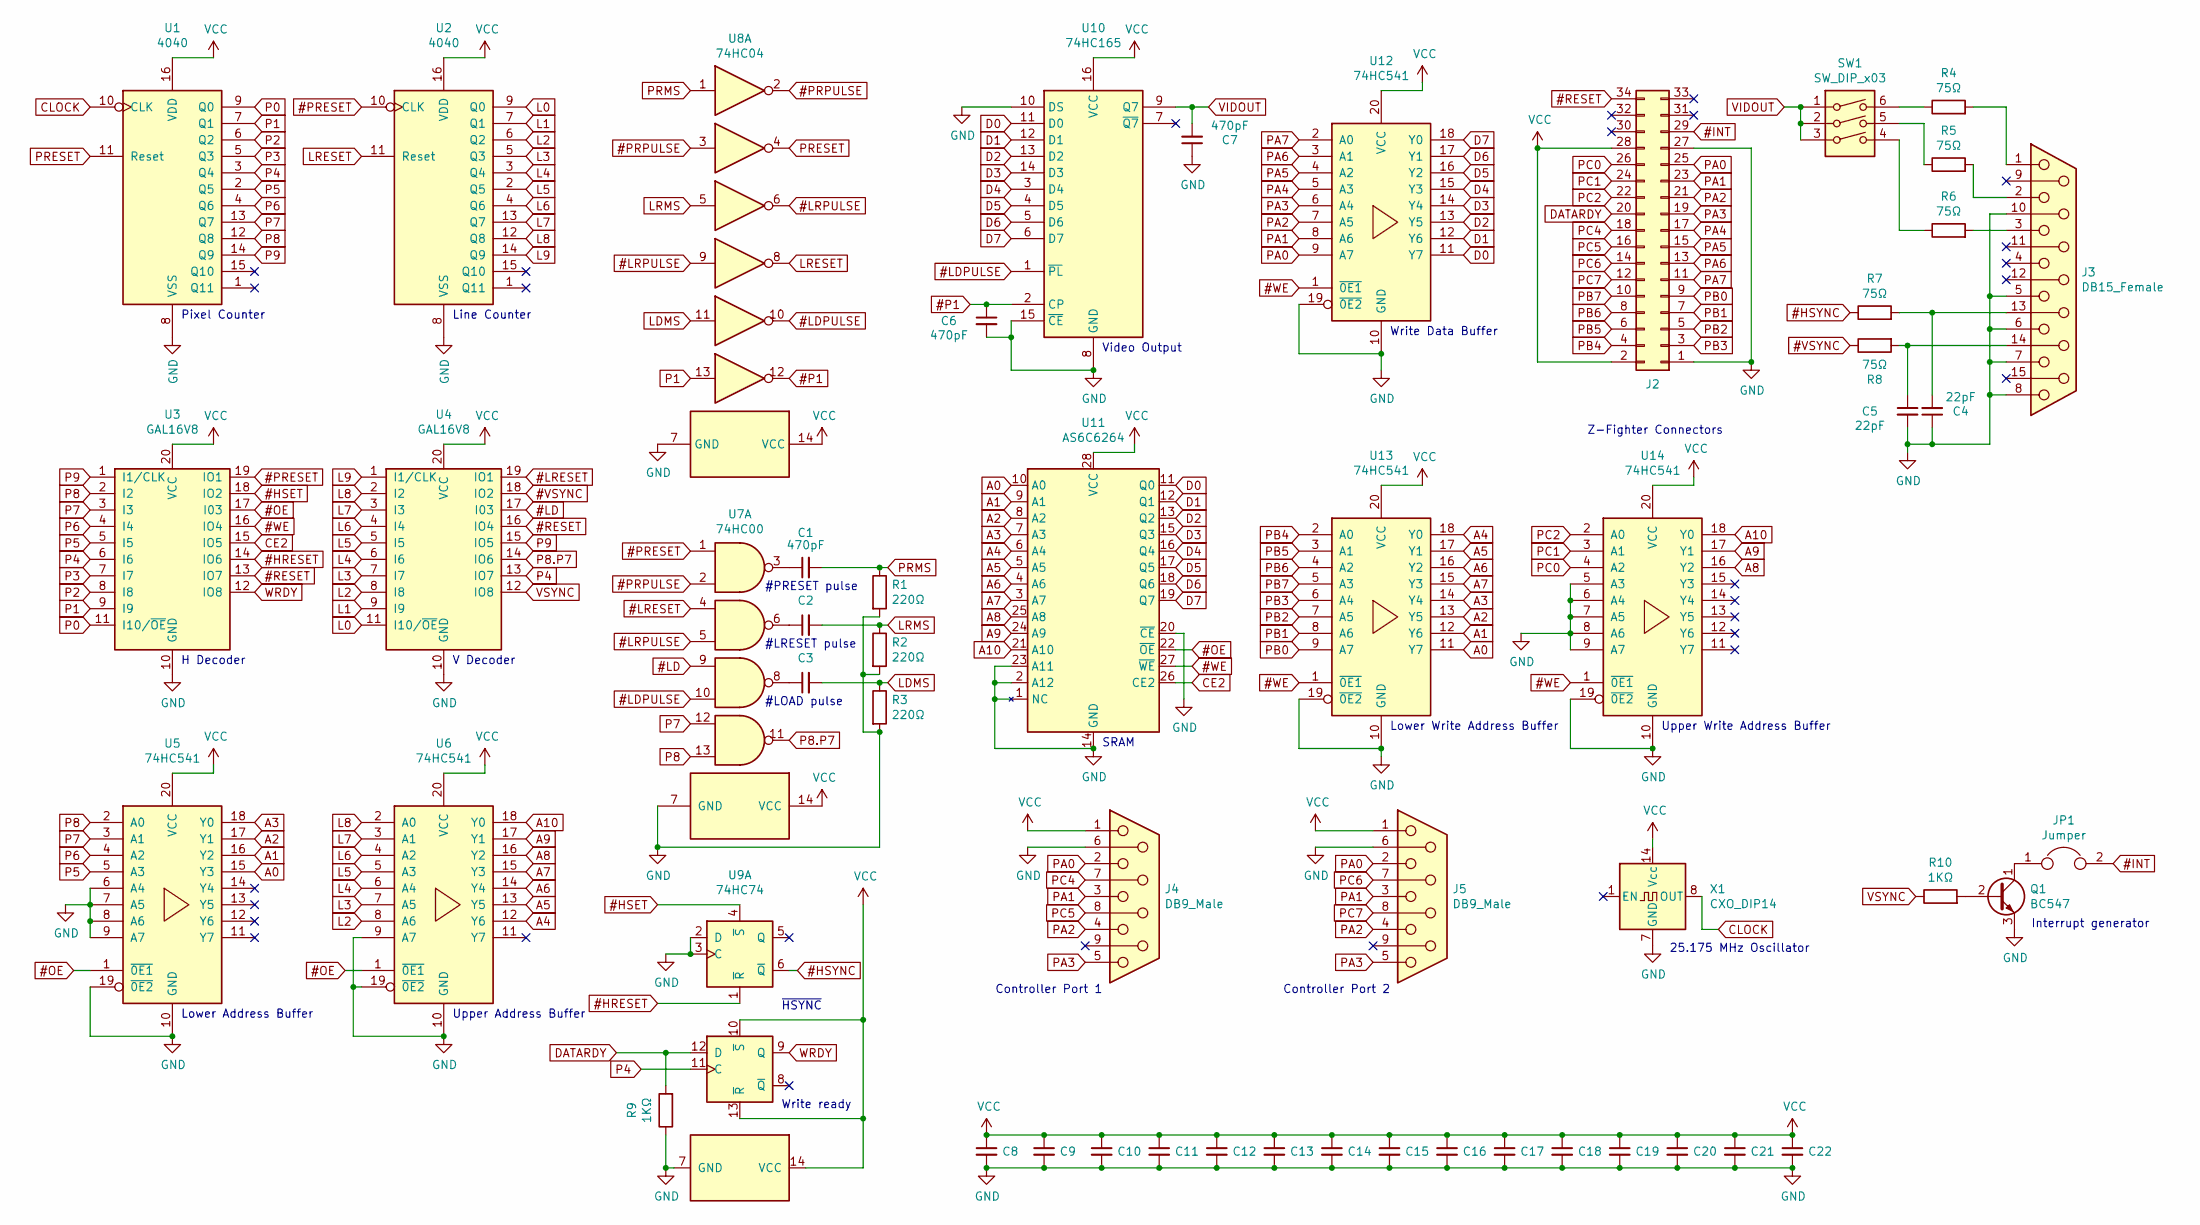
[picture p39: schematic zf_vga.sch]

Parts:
C1, C2, C3, C6, C7: 470pF; C_Disc_D7.5mm_W2.5mm_P5.00mm
C4, C5: 22pF; C_Disc_D7.5mm_W2.5mm_P5.00mm
C8, C9, C10, C11, C12, C13, C14, C15, C16, C17, C18, C19, C20, C21, C22: 0.1uF; C_Disc_D7.5mm_W2.5mm_P5.00mm
J2: Z-FIGHTER Expansion Port; Z-FIGHTER_Expansion_Port
J3: DB15_Female; DSUB-15-HD_Female_Horizontal_P2.29x1.98mm_EdgePinOffset8.35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
J4, J5: DB9_Male; DSUB-9_Male_Horizontal_P2.77x2.84mm_EdgePinOffset7.70mm_Hou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
JP1: Jumper
Q1: BC547; TO-92_Inline_Wide
R1, R2, R3: 220Ω; R_Axial_DIN0207_L6.3mm_D2.5mm_P7.62mm_Horizontal
R4, R5, R6, R7, R8: 75Ω; R_Axial_DIN0207_L6.3mm_D2.5mm_P7.62mm_Horizontal
R9, R10: 1KΩ; R_Axial_DIN0207_L6.3mm_D2.5mm_P7.62mm_Horizontal
SW1: SW_DIP_x03; DIP-6_W7.62mm_LongPads
U1, U2: 4040; DIP-16_W7.62mm_LongPads
U3, U4: GAL16V8; DIP-20_W7.62mm_LongPads
U5, U6, U12, U13, U14: 74HC541; DIP-20_W7.62mm_LongPads
U7: 74HC00; DIP-14_W7.62mm_LongPads
U8: 74HC04; DIP-14_W7.62mm_LongPads
U9: 74HC74; DIP-14_W7.62mm_LongPads
U10: 74HC165; DIP-16_W7.62mm_LongPads
U11: AS6C6264; DIP-28_W15.24mm_LongPads
X1: CXO_DIP14; Oscillator_DIP-14_LargePads

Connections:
#HRESET: U3.14 (IO6), U9.1 (~R)
#HSET: U3.18 (IO2), U9.4 (~S)
#HSYNC: R7.1, U9.6 (~Q)
#INT: J2.29, JP1.2
#LD: U4.17 (I03), U7.9
#LDPULSE: U7.10, U8.10, U10.1 (~PL)
#LRESET: U4.19 (IO1), U7.4
#LRPULSE: U7.5, U8.6, U8.9
#OE: U3.17 (I03), U5.1 (~0E1), U6.1 (~0E1), U11.22 (~OE)
#P1: C6.1, U8.12, U10.2 (CP)
#PRESET: U2.10 (CLK), U3.19 (IO1), U7.1
#PRPULSE: U7.2, U8.2, U8.3
#RESET: J2.34, U3.13 (IO7), U4.16 (IO4)
#VSYNC: R8.1, U4.18 (IO2)
#WE: U3.16 (IO4), U11.27 (~WE), U12.1 (~0E1), U13.1 (~0E1), U14.1 (~0E1)
A0: U5.15 (Y3), U11.10 (A0), U13.11 (Y7)
A1: U5.16 (Y2), U11.9 (A1), U13.12 (Y6)
A2: U5.17 (Y1), U11.8 (A2), U13.13 (Y5)
A3: U5.18 (Y0), U11.7 (A3), U13.14 (Y4)
A4: U6.12 (Y6), U11.6 (A4), U13.18 (Y0)
A5: U6.13 (Y5), U11.5 (A5), U13.17 (Y1)
A6: U6.14 (Y4), U11.4 (A6), U13.16 (Y2)
A7: U6.15 (Y3), U11.3 (A7), U13.15 (Y3)
A8: U6.16 (Y2), U11.25 (A8), U14.16 (Y2)
A9: U6.17 (Y1), U11.24 (A9), U14.17 (Y1)
A10: U6.18 (Y0), U11.21 (A10), U14.18 (Y0)
CE2: U3.15 (IO5), U11.26 (CE2)
CLOCK: U1.10 (CLK), X1.5, X1.8 (OUT); also elsewhere on the board
D0: U10.11 (D0), U11.11 (Q0), U12.11 (Y7)
D1: U10.12 (D1), U11.12 (Q1), U12.12 (Y6)
D2: U10.13 (D2), U11.13 (Q2), U12.13 (Y5)
D3: U10.14 (D3), U11.15 (Q3), U12.14 (Y4)
D4: U10.3 (D4), U11.16 (Q4), U12.15 (Y3)
D5: U10.4 (D5), U11.17 (Q5), U12.16 (Y2)
D6: U10.5 (D6), U11.18 (Q6), U12.17 (Y1)
D7: U10.6 (D7), U11.19 (Q7), U12.18 (Y0)
DATARDY: J2.20, R9.2, U9.12 (D)
GND: C4.1, C5.2, C6.2, C7.1, C8.2, C9.2, C10.2, C11.2, C12.2, C13.2, C14.2, C15.2, C16.2, C17.2, C18.2, C19.2, C20.2, C21.2, C22.2, J2.1, J2.27, J3.5, J3.6, J3.7, J3.8, J3.10, J4.6, J5.6, Q1.3 (E), R1.2, R2.2, R3.2, R9.1, U1.8 (VSS), U2.8 (VSS), U3.10 (GND), U4.10 (GND), U5.6 (A4), U5.7 (A5), U5.8 (A6), U5.9 (A7), U5.10 (GND), U5.19 (~0E2), U6.9 (A7), U6.10 (GND), U6.19 (~0E2), U7.7 (GND), U8.7 (GND), U9.2 (D), U9.3 (C), U9.7 (GND), U10.8 (GND), U10.10 (DS), U10.15 (~CE), U11.1 (NC), U11.2 (A12), U11.14 (GND), U11.20 (~CE), U11.23 (A11), U12.10 (GND), U12.19 (~0E2), U13.10 (GND), U13.19 (~0E2), U14.5 (A3), U14.6 (A4), U14.7 (A5), U14.8 (A6), U14.9 (A7), U14.10 (GND), U14.19 (~0E2), X1.4, X1.7 (GND); also elsewhere on the board
L0: U2.9 (Q0), U4.11 (I10/~OE~)
L1: U2.7 (Q1), U4.9 (I9)
L2: U2.6 (Q2), U4.8 (I8), U6.8 (A6)
L3: U2.5 (Q3), U4.7 (I7), U6.7 (A5)
L4: U2.3 (Q4), U4.6 (I6), U6.6 (A4)
L5: U2.2 (Q5), U4.5 (I5), U6.5 (A3)
L6: U2.4 (Q6), U4.4 (I4), U6.4 (A2)
L7: U2.13 (Q7), U4.3 (I3), U6.3 (A1)
L8: U2.12 (Q8), U4.2 (I2), U6.2 (A0)
L9: U2.14 (Q9), U4.1 (I1/CLK)
LDMS: C3.2, R3.1, U8.11
LRESET: U2.11 (Reset), U8.8
LRMS: C2.2, R2.1, U8.5
unnamed: C1.1, U7.3
unnamed: C2.1, U7.6
unnamed: C3.1, U7.8
unnamed: C4.2, J3.13, R7.2
unnamed: C5.1, J3.14, R8.2
unnamed: J3.1, R4.2
unnamed: J3.2, R5.2
unnamed: J3.3, R6.2
unnamed: JP1.1, Q1.1 (C)
unnamed: Q1.2 (B), R10.2
unnamed: R4.1, SW1.6
unnamed: R5.1, SW1.5
unnamed: R6.1, SW1.4
P0: U1.9 (Q0), U3.11 (I10/~OE~)
P1: U1.7 (Q1), U3.9 (I9), U8.13
P2: U1.6 (Q2), U3.8 (I8)
P3: U1.5 (Q3), U3.7 (I7)
P4: U1.3 (Q4), U3.6 (I6), U4.13 (IO7), U9.11 (C)
P5: U1.2 (Q5), U3.5 (I5), U5.5 (A3)
P6: U1.4 (Q6), U3.4 (I4), U5.4 (A2)
P7: U1.13 (Q7), U3.3 (I3), U5.3 (A1), U7.12
P8: U1.12 (Q8), U3.2 (I2), U5.2 (A0), U7.13
P8.P7: U4.14 (IO6), U7.11
P9: U1.14 (Q9), U3.1 (I1/CLK), U4.15 (IO5)
PA0: J2.25, J4.2, J5.2, U12.9 (A7)
PA1: J2.23, J4.3, J5.3, U12.8 (A6)
PA2: J2.21, J4.4, J5.4, U12.7 (A5)
PA3: J2.19, J4.5, J5.5, U12.6 (A4)
PA4: J2.17, U12.5 (A3)
PA5: J2.15, U12.4 (A2)
PA6: J2.13, U12.3 (A1)
PA7: J2.11, U12.2 (A0)
PB0: J2.9, U13.9 (A7)
PB1: J2.7, U13.8 (A6)
PB2: J2.5, U13.7 (A5)
PB3: J2.3, U13.6 (A4)
PB4: J2.4, U13.2 (A0)
PB5: J2.6, U13.3 (A1)
PB6: J2.8, U13.4 (A2)
PB7: J2.10, U13.5 (A3)
PC0: J2.26, U14.4 (A2)
PC1: J2.24, U14.3 (A1)
PC2: J2.22, U14.2 (A0)
PC4: J2.18, J4.7
PC5: J2.16, J4.8
PC6: J2.14, J5.7
PC7: J2.12, J5.8
PRESET: U1.11 (Reset), U8.4
PRMS: C1.2, R1.1, U8.1
VCC: C8.1, C9.1, C10.1, C11.1, C12.1, C13.1, C14.1, C15.1, C16.1, C17.1, C18.1, C19.1, C20.1, C21.1, C22.1, J2.2, J2.28, J4.1, J5.1, U1.16 (VDD), U2.16 (VDD), U3.20 (VCC), U4.20 (VCC), U5.20 (VCC), U6.20 (VCC), U7.14 (VCC), U8.14 (VCC), U9.10 (~S), U9.13 (~R), U9.14 (VCC), U10.16 (VCC), U11.28 (VCC), U12.20 (VCC), U13.20 (VCC), U14.20 (VCC), X1.14 (Vcc); also elsewhere on the board
VIDOUT: C7.2, SW1.1, SW1.2, SW1.3, U10.9 (Q7)
VSYNC: R10.1, U4.12 (IO8)
WRDY: U3.12 (IO8), U9.9 (Q)

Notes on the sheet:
Line Counter
SRAM
Write ready
~HSYNC
Video Output
Controller Port 2
Controller Port 1
Lower Write Address Buffer
Upper Write Address Buffer
Z-Fighter Connectors
25.175 MHz Oscillator
Upper Address Buffer
Lower Address Buffer
V Decoder
H Decoder
#PRESET pulse
#LRESET pulse
Write Data Buffer
Pixel Counter
Interrupt generator
#LOAD pulse

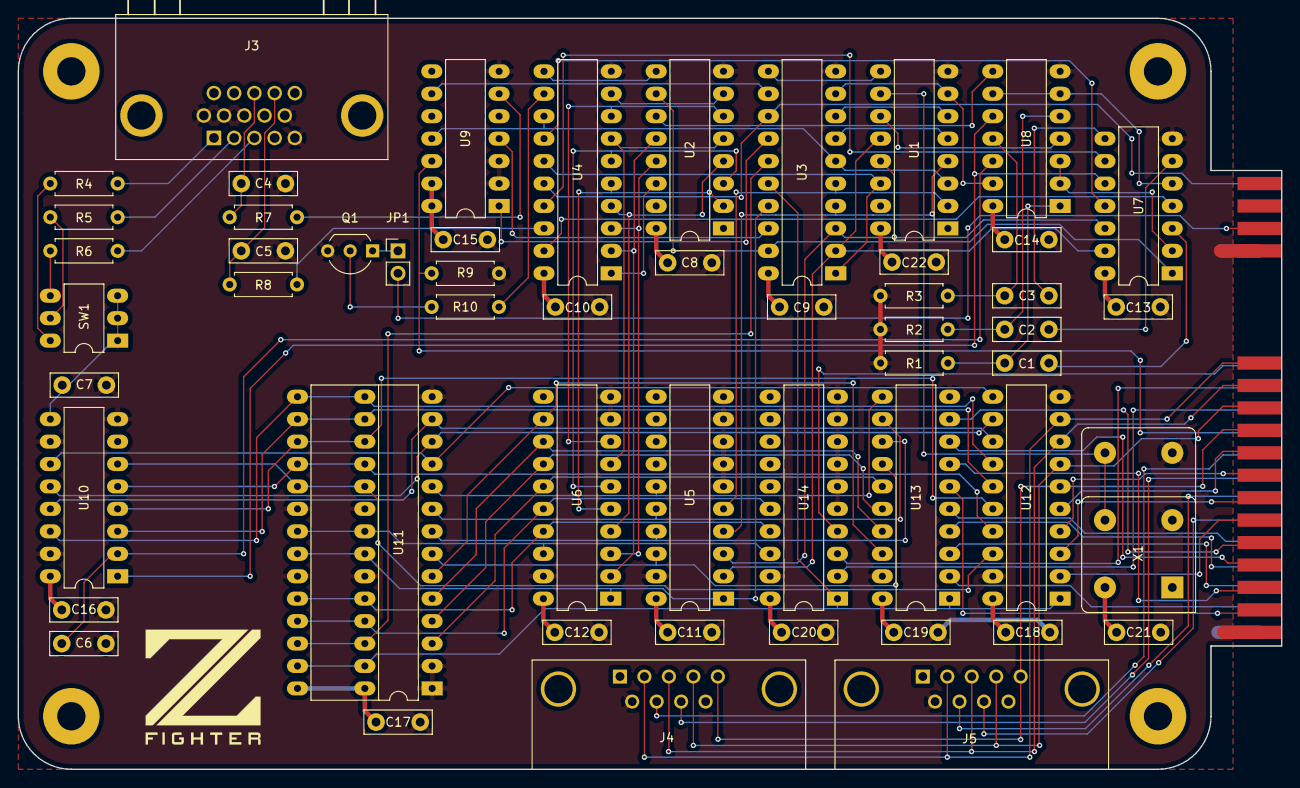
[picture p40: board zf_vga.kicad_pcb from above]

Board: 2 copper layers, 143.0 x 85.0 mm, 59 parts (0 on the bottom side), 104 nets.

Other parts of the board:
Mount1, Mount2, Mount3, Mount4: MountingHole_3.2mm_M3_Pad
X1#2: CXO_DIP14; Oscillator_DIP-14_LargePads

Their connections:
CLOCK: X1#2.8; also elsewhere on the board
GND: X1#2.7; also elsewhere on the board
VCC: X1#2.14; also elsewhere on the board

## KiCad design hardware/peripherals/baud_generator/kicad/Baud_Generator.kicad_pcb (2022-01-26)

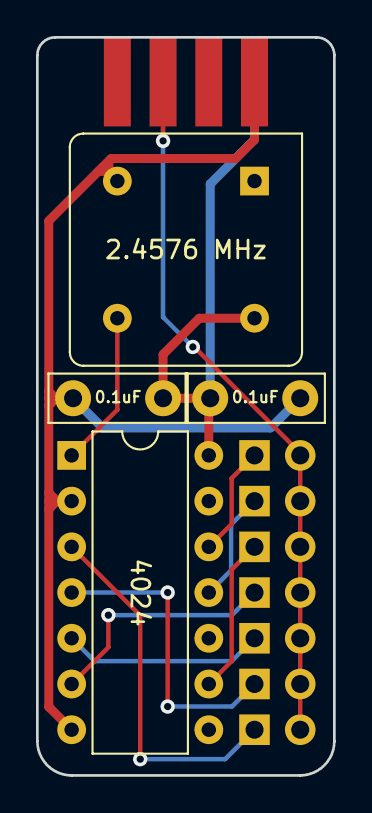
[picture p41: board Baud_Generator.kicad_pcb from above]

Board: 2 copper layers, 16.5 x 41.0 mm, 6 parts (0 on the bottom side), 11 nets.

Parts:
0.1uF: 0.1uF; C_Disc_D7.5mm_W2.5mm_P5.00mm
C2: 0.1uF; C_Disc_D7.5mm_W2.5mm_P5.00mm
J1: Conn_02x04_Odd_Even; ZF_CPU_Control_Header
J2: Conn_02x07_Odd_Even; PinHeader_2x07_P2.54mm_Vertical
U1: 4024; DIP-14_W7.62mm
X1: 2.4576 MHz; Oscillator_DIP-8

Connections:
CLOCK2: J1.5, J2.2, J2.4, J2.6, J2.8, J2.10, J2.12, J2.14
GND: 0.1uF.2, C2.2, J1.1, U1.2, U1.7, X1.4
unnamed: J2.1, U1.12
unnamed: J2.3, U1.11
unnamed: J2.5, U1.9
unnamed: J2.7, U1.6
unnamed: J2.9, U1.5
unnamed: J2.11, U1.4
unnamed: J2.13, U1.3
unnamed: U1.1, X1.5
VCC: 0.1uF.1, C2.1, J1.2, U1.14, X1.8

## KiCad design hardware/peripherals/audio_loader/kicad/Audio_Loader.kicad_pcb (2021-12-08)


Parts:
C1, C2, C3, C5, C6, C7, C8: 0.1uF; C_Disc_D7.5mm_W2.5mm_P5.00mm
C4: 330pF; C_Disc_D7.5mm_W2.5mm_P5.00mm
D1: 1N4148; D_DO-35_SOD27_P7.62mm_Horizontal
D2: LED; LED_D5.0mm
J1: USB PWR; USB_Micro-B_Amphenol_10118194_Horizontal
J2: DE-9 Female; DSUB-9_Female_Horizontal_P2.77x2.84mm_EdgePinOffset4.94mm_H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
J3: TS Jack; Jack_3.5mm_CUI_SJ1-3533NG_Horizontal
JP1: Jumper_3_Open; PinHeader_1x03_P2.54mm_Vertical
Q1: BC547; TO-92_Inline_Wide
R1: 1MΩ; R_Axial_DIN0207_L6.3mm_D2.5mm_P7.62mm_Horizontal
R3: 1KΩ; R_Axial_DIN0207_L6.3mm_D2.5mm_P7.62mm_Horizontal
RN1: 1KΩ; R_Array_SIP5
RN2: 1KΩ; R_Array_SIP4
U1: LM741; DIP-8_W7.62mm
U2: LM393; DIP-8_W7.62mm
U3: MAX202; DIP-16_W7.62mm

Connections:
GND: C1.2, C2.2, C3.2, C4.1, C8.2, J1.5 (GND), J1.6 (Shield), J2.0 (PAD), J2.5, J3.S, Q1.3 (E), R1.2, RN2.1 (common), U1.4 (V-), U2.4 (V-), U3.15 (GND)
unnamed: C4.2, D1.1 (K), R1.1, U2.3 (+)
unnamed: C5.1, U3.3 (C1-)
unnamed: C5.2, U3.1 (C1+)
unnamed: C6.2, U3.2 (VS+)
unnamed: C7.1, U3.4 (C2+)
unnamed: C7.2, U3.5 (C2-)
unnamed: C8.1, U3.6 (VS-)
unnamed: D1.2 (A), U1.6
unnamed: J1.1 (VBUS), JP1.3 (B)
unnamed: J2.2, U3.14 (T1OUT)
unnamed: J3.T, U1.3 (+)
unnamed: Q1.2 (B), R3.2
PIN_9: J2.9, JP1.1 (A)
RN1a: RN1.5 (R4), RN2.3 (R2), U2.2 (-), U2.5 (+)
RN1b: R3.1, RN1.4 (R3), U2.1
RN1c: D2.1 (K), Q1.1 (C), RN1.2 (R1), U3.11 (T1IN)
RN1d: D2.2 (A), RN1.3 (R2)
RN2a: RN2.2 (R1), U1.2 (-)
RN2c: RN2.4 (R3), U2.6 (_)
VCC: C1.1, C2.1, C3.1, C6.1, JP1.2 (C), RN1.1 (common), U1.7 (V+), U2.8 (V+), U3.16 (VCC)


Board: 2 copper layers, 55.9 x 38.1 mm, 22 parts (0 on the bottom side), 21 nets.

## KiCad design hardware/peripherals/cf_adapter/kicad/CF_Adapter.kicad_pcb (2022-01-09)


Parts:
J1: Z-Fighter IDE Connector; PinHeader_2x20_P2.54mm_Vertical
J2: Conn_02x25_Top_Bottom; CF-Card_3M_N7E50-7516PK-20-WF
R1: 1KΩ; R_1206_3216Metric_Pad1.30x1.75mm_HandSolder

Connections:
#CFCS: J1.37, J2.7
#RD: J1.25, J2.34
#RESET: J1.1, J2.41
#WR: J1.23, J2.35
A0: J1.35, J2.20
A1: J1.33, J2.19
A2: J1.36, J2.18
D0: J1.17, J2.21
D1: J1.15, J2.22
D2: J1.13, J2.23
D3: J1.11, J2.2
D4: J1.9, J2.3
D5: J1.7, J2.4
D6: J1.5, J2.5
D7: J1.3, J2.6
GND: J1.2, J1.19, J1.22, J1.24, J1.26, J1.30, J1.40, J2.1, J2.8, J2.9, J2.10, J2.11, J2.12, J2.14, J2.15, J2.16, J2.17, J2.39, J2.50
unnamed: J2.36, R1.2
PATA29: J1.29, J2.44
PATA34: J1.34, J2.46
PATA38: J1.38, J2.32
VCC: J1.20, J2.13, J2.38, R1.1


Board: 2 copper layers, 27.0 x 53.3 mm, 3 parts (0 on the bottom side), 21 nets.

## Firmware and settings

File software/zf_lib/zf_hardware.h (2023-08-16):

// Hardware definitions for Z-Fighter
// by Tangent 2021

#ifndef ZF_HARDWARE_H
#define ZF_HARDWARE_H

#define ROMDISABLE_n    0x38

// 8255A Programmable Peripheral Interface (Accessory)
#define PPI_ACC         0x40
#define PORTA_ACC       PPI_ACC+0   // Connected to key switches
#define PORTB_ACC       PPI_ACC+1   // Connected to ST7920 LCD data bus
#define PORTC_ACC       PPI_ACC+2   // Connected to LCD control signals, backlight and buzzer
#define CTRL_ACC        PPI_ACC+3   // PPI control port

// BSR (Bit Set/Reset) control words (Accessory)
#define LCD_E_LO        0x00        // LCD E (Enable) low
#define LCD_E_HI        0x01        // LCD E (Enable) high
#define LCD_WR          0x02        // LCD R/#W low (Write)
#define LCD_RD          0x03        // LCD R/#W high (Read)
#define LCD_INST        0x04        // LCD RS low (Instruction)
#define LCD_DATA        0x05        // LCD RS high (Data)
#define LCD_BL_OFF      0x06        // LCD backlight off
#define LCD_BL_ON       0x07        // LCD backlight on
#define BUZZER_OFF      0x0E        // Electromagnetic buzzer off
#define BUZZER_ON       0x0F        // Electromagnetic buzzer on

// 8255A Programmable Peripheral Interface (User)
#define PPI_USER        0x80
#define PORTA           PPI_USER+1  // User port PA7-PA0
#define PORTB           PPI_USER+2  // User port PB7-PB0
#define PORTC           PPI_USER+3  // User port PC7-PC0
#define CTRL            PPI_USER+4  // User PPI control port

// Z80 SIO/0 Serial Input/Output Controller
#define SIO             0x00
#define SIO_A           SIO+0       // SIO channel A data port
#define SIO_B           SIO+1       // SIO channel B data port
#define SIO_AC          SIO+2       // SIO channel A control port
#define SIO_BC          SIO+3       // SIO channel B control port

// CompactFlash
#define CF0             0x10        // CF data I/O
#define CF1             CF0+1       // Error register (/RD), Feature (/WR)
#define CF2             CF0+2       // Sector count
#define CF3             CF0+3       // Sector address LBA 0 [0:7]
#define CF4             CF0+4       // Sector address LBA 1 [8:15]
#define CF5             CF0+5       // Sector address LBA 2 [16:23]
#define CF6             CF0+6       // Sector address LBA 3 [24:27 (LSB)]
#define CF7             CF0+7       // Status (/RD), Command (/WR)

#endif

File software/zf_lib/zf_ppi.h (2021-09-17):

// 8255A Programmable Peripheral Interface definitions for Z-Fighter
// (User parallel port)
// by Tangent 2021

#ifndef ZF_PPI_H
#define ZF_PPI_H

#include <zf_hardware.h>

// User port pinout (male side):
// ╔══════════════════    ═══════════════════╗
// ║ A0 A1 A2 A3 A4 A5 A6 A7 B0 B1 B2 B3 GND ║
// ║ C0 C1 C2 C3 C4 C5 C6 C7 B7 B6 B5 B4 VCC ║
// ╚═════════════════════════════════════════╝

// Before I/O, the PPI must be initialized by writing a control word to its control port.
// '0' will set a port as output, '1' will set a port as input.
// Example: ctrl = 0b1001000; // I/O Mode 0, port A = input, port B = output, port Cu/Cl output.
//
// D7:      Always '1' for I/O mode.
// D6-D5:   Group A Mode Selection:      00 = Mode 1
//                                       01 = Mode 0
//                                       1x = Mode 2
// D4:      Port A
// D3:      Port Cu (PC7-PC4)
// D2:      Group B Mode Selection:      0 = Mode 0
//                                       1 = Mode 1
// D1:      Port B
// D0:      Port Cl (PC3-PC0)

// Special Function Registers (SFR) for 8-bit I/O ports:
// Example: pa = foo;   // Write to port A
//          bar = pb;   // Read from port B
            
__sfr __at PORTA pa;
__sfr __at PORTB pb;
__sfr __at PORTC pc;
__sfr __at CTRL  ctrl;

// BSR (Bit Set/Reset) control words:
// Always use these values as definitions for pins on port C.
// Write the value of the bit to the control port to RESET a pin on port C.
// Write the value of the bit +1 to SET a pin on port C.
// Example: ctrl = c0+1; // SET port C pin 1.

#define c0 0x00
#define c1 0x02
#define c2 0x04
#define c3 0x06
#define c4 0x08
#define c5 0x0A
#define c6 0x0C
#define c7 0x0E

// Define bit order for serial read/write functions. Default is MSB first.
// Subsequent calls of serialRead and serialWrite will use bit order specified.
// Example: bitOrder = LSB;
extern unsigned char bitOrder;

#define MSB 0
#define LSB 1

// Read byte serially from a pin on port C, pulsing clock pin high after each bit.
// Connect 'MISO' to an input port on port C. Connect 'CLK' to an output pin on port C.
// Example: serialRead(c0,c4);	// Read a byte serially from port C pin 0.
unsigned char serialRead(unsigned char dataPin, unsigned char clockPin);

// Write byte serially to a pin on port C, pulsing clock pin high after each bit.
// Connect 'MOSI' to an output port on port C. Connect 'CLK' to an output pin on port C.
// Example: serialWrite(c4,c0);	// Write a byte serially from port C pin 4.
void serialWrite(unsigned char byte, unsigned char dataPin, unsigned char clockPin);

// Test a bit (0-7) in a byte and return 0 if bit is reset or 1 if bit is set.
unsigned char bitTest(char bit, char byte);

// Reverse order of all bits in a byte.
unsigned char byteReverse(char byte) __z88dk_fastcall;

// Convert a BCD (binary-coded decimal) value to binary.
unsigned char bcd2bin(unsigned char bcd);

// Convert a two-digit (<100) binary value to BCD.
unsigned char bin2bcd(unsigned char bin);

#endif

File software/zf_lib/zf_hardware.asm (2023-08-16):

; Hardware definitions for Z-Fighter
; Imported from <zf_hardware.h>
; by Tangent 2021

EXTERN      _romdisable_n
EXTERN      _porta_acc
EXTERN      _portb_acc
EXTERN      _portc_acc
EXTERN      _ctrl_acc
EXTERN      _lcd_e_lo
EXTERN      _lcd_e_hi
EXTERN      _lcd_wr
EXTERN      _lcd_rd
EXTERN      _lcd_inst
EXTERN      _lcd_data
EXTERN      _lcd_bl_off
EXTERN      _lcd_bl_on
EXTERN      _buzzer_off
EXTERN      _buzzer_on
EXTERN      _porta
EXTERN      _portb
EXTERN      _portc
EXTERN      _ctrl
EXTERN      _sio
EXTERN      _sio_a
EXTERN      _sio_b
EXTERN      _sio_ac
EXTERN      _sio_bc
EXTERN      _cf0
EXTERN      _cf1
EXTERN      _cf2
EXTERN      _cf3
EXTERN      _cf4
EXTERN      _cf5
EXTERN      _cf6
EXTERN      _cf7

ROMDISABLE_n    EQU    _romdisable_n

PORTA_ACC       EQU     _porta_acc
PORTB_ACC       EQU     _portb_acc
PORTC_ACC       EQU     _portc_acc
CTRL_ACC        EQU     _ctrl_acc

LCD_E_LO        EQU     _lcd_e_lo
LCD_E_HI        EQU     _lcd_e_hi
LCD_WR          EQU     _lcd_wr
LCD_RD          EQU     _lcd_rd
LCD_INST        EQU     _lcd_inst
LCD_DATA        EQU     _lcd_data
LCD_BL_OFF      EQU     _lcd_bl_off
LCD_BL_ON       EQU     _lcd_bl_on
BUZZER_OFF      EQU     _buzzer_off
BUZZER_ON       EQU     _buzzer_on

PORTA           EQU     _porta
PORTB           EQU     _portb
PORTC           EQU     _portc
CTRL            EQU     _ctrl

SIO             EQU     _sio
SIO_A           EQU     _sio_a
SIO_B           EQU     _sio_b
SIO_AC          EQU     _sio_ac
SIO_BC          EQU     _sio_bc

CF0             EQU     _cf0
CF1             EQU     _cf1
CF2             EQU     _cf2
CF3             EQU     _cf3
CF4             EQU     _cf4
CF5             EQU     _cf5
CF6             EQU     _cf6
CF7             EQU     _cf7

PUBLIC          ROMDISABLE_n

PUBLIC          PORTA_ACC
PUBLIC          PORTB_ACC
PUBLIC          PORTC_ACC
PUBLIC          CTRL_ACC
PUBLIC          LCD_E_LO
PUBLIC          LCD_E_HI
PUBLIC          LCD_WR
PUBLIC          LCD_RD
PUBLIC          LCD_INST
PUBLIC          LCD_DATA
PUBLIC          LCD_BL_OFF
PUBLIC          LCD_BL_ON
PUBLIC          BUZZER_OFF
PUBLIC          BUZZER_ON
PUBLIC          PORTA
PUBLIC          PORTB
PUBLIC          PORTC
PUBLIC          CTRL
PUBLIC          SIO
PUBLIC          SIO_A
PUBLIC          SIO_B
PUBLIC          SIO_AC
PUBLIC          SIO_BC
PUBLIC          CF0
PUBLIC          CF1
PUBLIC          CF2
PUBLIC          CF3
PUBLIC          CF4
PUBLIC          CF5
PUBLIC          CF6
PUBLIC          CF7

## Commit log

2021-03-26 Annotated Mainboard schematic
    [Z-FIGHTER_Mainboard.sch]
2021-08-02 Added battery loop slits to case rear and PrusaSlicer .3MF files with recommended print settings
    [Z-FIGHTER_Case_Bottom.STL, Z-FIGHTER_Case_Front.3mf, Z-FIGHTER_Case_Front.STL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]
2021-08-12 Updated Accessory Board schema
    [Z-FIGHTER_Accessory_Board.sch]
2021-08-12 Cleaned up mainboard schema
    [Z-FIGHTER_Mainboard.sch]
2021-08-12 Increased tolerances
    [Z-FIGHTER_Case_Front.3mf, Z-FIGHTER_Case_Front.STL, Z-FIGHTER_Case_Rear.3mf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]
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2021-08-19 Initial submit
    [Z-FIGHTER_Mainboard.kicad_pcb, Z-FIGHTER_Mainboard.sch]
2021-08-20 Routing progress
    [Z-FIGHTER_Mainboard.kicad_pcb]
2021-08-20 Improved power delivery
    [Z-FIGHTER_Mainboard.kicad_pcb, Z-FIGHTER_Mainboard.sch]
2021-08-20 Tweaked routing
    [Z-FIGHTER_Mainboard.kicad_pcb]
2021-08-20 Fixed silkscreen
    [Z-FIGHTER_Mainboard.kicad_pcb]
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2021-08-25 Expanded I/O opening for CPU control header
    [Z-FIGHTER_Case_Rear.3mf, Z-FIGHTER_Case_Rear.STL]
2021-08-25 Final routing for rev. 2
    [Z-FIGHTER_Mainboard.kicad_pcb]
2021-08-25 Final silkscreen rev.2
    [Z-FIGHTER_Mainboard.kicad_pcb]
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2021-09-03 Tweaked schema
    [Z-FIGHTER_Mainboard.sch]
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2021-09-16 zf_build improvements
    Made sure assembler/linker use zf_lib (huge improvement in build times), fixed zf_lib building in the source file's working directory, removed non-user defined paths from user config, renamed user config,
2021-09-21 Changed SRAM silkscreen, moved C1, adjusted U6 ground path
    [Z-FIGHTER_Mainboard.kicad_pcb]
2021-09-23 Accessory board rev. 1b
    Adjusted accessory board LCD connector pins to be 7.62mm (2.54mm*3) apart from pins on LCD board for easier bridging
    [Z-FIGHTER_Accessory_Board.kicad_pcb]
2021-09-23 Gerber settings
    [Z-FIGHTER_Accessory_Board.kicad_pcb]
2021-09-23 Added drawing of LCD module
    [Z-FIGHTER_Accessory_Board.kicad_pcb]
2021-09-23 LCD bridge board
    [LCD_Bridge.kicad_pcb, LCD_Bridge.sch]
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2021-09-24 Fixed bypass
    [Z-FIGHTER_Mainboard.kicad_pcb, Z-FIGHTER_Mainboard.sch]
2021-09-25 Changed SRAM silkscreen back to '4008
    [Z-FIGHTER_Mainboard.kicad_pcb, Z-FIGHTER_Mainboard.sch]
2021-11-12 Added Compact Flash adapter files
    [CF_Adapter.kicad_pcb, CF_Adapter.sch]
2021-11-13 Initial submit of baud rate generator module files
    [Baud_Generator.kicad_pcb, Baud_Generator.sch]
2021-11-13 Progress on Baud Generator PCB
    [Baud_Generator.kicad_pcb, Baud_Generator.sch]
2021-11-14 Completed baud rate generator PCB
    [Baud_Generator.kicad_pcb]
2021-11-14 Corrections to baud rate generator
    [Baud_Generator.kicad_pcb]
2021-11-16 Initial commit of audio loader files
    [Audio_Loader.kicad_pcb, Audio_Loader.sch]
2021-11-16 Initial commit of audio loader pcb
    [Audio_Loader.kicad_pcb, Audio_Loader.sch]
2021-11-17 Audio Loader PCB Rev. 0
    [Audio_Loader.kicad_pcb, Audio_Loader.sch]
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2021-11-20 Mainboard improvements
    Support for DIP-8 oscillators, replaced system clock pin on CPU control header with CPU #WAIT, added jumper to select internal/external CLOCK2
    [Z-FIGHTER_Accessory_Board.kicad_pcb, Z-FIGHTER_Mainboard.kicad_pcb]
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2021-11-20 Fixed copper pours
    [CF_Adapter.kicad_pcb]
2021-11-20 Fixed DIP-8 oscillator support
    [Z-FIGHTER_Mainboard.kicad_pcb]
2021-11-21 Changed edge connector, Gerber settings
    [Baud_Generator.kicad_pcb]
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2021-11-24 Flipped X1 bypass cap, tiny routing tweaks
    [Z-FIGHTER_Mainboard.kicad_pcb]
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2021-11-29 Changed schematic CF connector
    [CF_Adapter.sch]
2021-11-29 Redesigned CF adapter for low-profile socket
    [CF_Adapter.kicad_pcb]
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2021-12-08 Changed accessory parallel header footprint and silkscreen
    [Z-FIGHTER_Mainboard.kicad_pcb]
2021-12-08 Keyed corner of baud generator pcb
    [Baud_Generator.kicad_pcb]
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2022-01-01 mechzoom: fixed hp underflow when dying 2x in 1 frame
2022-01-09 Update CF_Adapter.kicad_pcb
    Flipped silkscreen to be right side up when installed in ZF
    [CF_Adapter.kicad_pcb]
2022-01-18 Case adjustment, schema update, layout image update, readme
    [Z-FIGHTER_Case_Rear.3mf, Z-FIGHTER_Case_Rear.STL, Z-FIGHTER_Mainboard.kicad_pcb]
2022-01-20 Stand modifications
    Reduced ZF height when placed in stand, increased width
    [Z-FIGHTER_Stand_Base.3mf, Z-FIGHTER_Stand_Base.STL, Z-FIGHTER_Stand_Side.STL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]
2022-01-21 Reorganized directories and content
    [Audio_Loader.kicad_pcb, Audio_Loader.sch, Baud_Generator.kicad_pcb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]
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2022-01-22 Changed connector footprint from 6 to 8 pins
    [Baud_Generator.kicad_pcb, Baud_Generator.sch]
2022-01-22 Added system clock to CPU control header
    [Z-FIGHTER_Mainboard-B_Cu.gbl, Z-FIGHTER_Mainboard-B_Mask.gbs, Z-FIGHTER_Mainboard-B_SilkS.gbo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]
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2022-01-26 Baud generator Gerber files
    [Baud_Generator-B_Cu.gbl, Baud_Generator-B_Mask.gbs, Baud_Generator-B_SilkS.gbo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]
2022-02-07 Changed 'Z' logo overhang hangle
    [Z-FIGHTER_Case_Front.3mf]
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2022-03-01 Added another NAND gate
    [zf_vga.sch]
2022-03-02 #LOAD pulse monostable circuit
    [zf_vga.sch]
2022-03-03 VRAM sharing, write timing
    [zf_vga.sch]
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2022-03-05 Replaced write address latches with buffers
    [zf_vga.sch]
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2022-03-06 Adjusted shift register load timings, synchronized pixel and line counters
    [zf_vga.sch]
2022-03-07 Changed /hsync to set/reset on flip flop, changed bus to /we and /oe
    [zf_vga.sch]
2022-03-09 Controller, VGA ports, adjusted write timings
    [zf_vga.sch]
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2022-03-13 Connected #RESET from ZF
    [zf_vga.kicad_pcb, zf_vga.sch]
2022-03-16 Routing draft, changed SRAM NC pin to VCC
    [zf_vga.kicad_pcb, zf_vga.sch]
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2022-03-17 Progress switching to 0.3mm via drill, 0.6mm via size
    [zf_vga.kicad_pcb]
2022-03-17 Fix all via clearances for 0.3mm via drill, 0.6mm via diameter
    [zf_vga-B_Cu.gbl, zf_vga-B_Mask.gbs, zf_vga-B_SilkS.gbo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]
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2022-03-18 Reduced pins of SRAM footprint
    [zf_vga-B_Cu.gbl, zf_vga-B_Mask.gbs, zf_vga-B_SilkS.gbo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]
2022-03-18 Silkscreen fixes
    [zf_vga-B_Cu.gbl, zf_vga-B_Mask.gbs, zf_vga-B_SilkS.gbo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]
2022-03-18 Fixed SRAM decoupling
    [zf_vga.kicad_pcb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]
2022-03-23 Flipped headers in schema for easier reference
    [Z-FIGHTER_Mainboard.sch]
2022-03-25 Replaced VGA connector footprint
    KiCad library horizontal D-SUB 15 footprint uses incorrect pin spacing.
    [zf_vga-B_Cu.gbl, zf_vga-B_Mask.gbs, zf_vga-B_SilkS.gbo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]
2022-03-28 VGA Module Rev. 1
    Fixed noise issues, added pull-up resistor to DATARDY
    [zf_vga-B_Cu.gbl, zf_vga-B_Mask.gbs, zf_vga-B_SilkS.gbo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]
2022-03-28 Moved VGA connector slightly
    [zf_vga-B_Cu.gbl, zf_vga-B_Mask.gbs, zf_vga-B_SilkS.gbo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]
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2022-03-31 Fixed edge cuts
    [zf_vga-B_Cu.gbl, zf_vga-B_Mask.gbs, zf_vga-B_SilkS.gbo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]
2022-03-31 Final controller and Gerber files
    [zf_vga_controller-B_Cu.gbl, zf_vga_controller-B_Mask.gbs, zf_vga_controller-B_SilkS.gbo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]
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2022-04-01 Moved components to back of board
    [zf_vga_controller-B_Cu.gbl, zf_vga_controller-B_Mask.gbs, zf_vga_controller-B_SilkS.gbo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]
2022-04-10 VGA Rev. 2
    Fixed VGA connector footprint, expanded joystick connectors for '241 buffer, added jumper-selectable interrupt generator
    [zf_vga-B_Cu.gbl, zf_vga-B_Mask.gbs, zf_vga-B_SilkS.gbo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]
2022-04-11 Redesigned controller around '241 buffer, added 2 extra buttons, increased height of PCB, added DE-9 connector
    [zf_vga_controller-B_Cu.gbl, zf_vga_controller-B_Mask.gbs, zf_vga_controller-B_SilkS.gbo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]
2022-04-11 U1 footprint to LongPads
    [zf_vga_controller.kicad_pcb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]
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2022-04-25 Fixed WRDY pin
2022-04-27 VGA Controller enclosure files
    [Z-FIGHTER_Controller_Front.3mf, Z-FIGHTER_Controller_Front.STL, Z-FIGHTER_Controller_Rear.3mf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]
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2022-05-12 Fixed interrupt circuit, routing improvements
    [zf_vga-B_Cu.gbl, zf_vga-B_Mask.gbs, zf_vga-B_SilkS.gbo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]
2022-05-12 Disable interrupts during buzzer routine
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2022-08-05 Schematic media, fixes
    [zf_vga.kicad_pcb, zf_vga.sch, zf_vga_controller.sch]
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2023-04-14 Routing, plot, mainboard images
    [Z-FIGHTER_Mainboard.kicad_pcb]
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2023-04-15 Change digi-key link to female DE-9
    [usb_serial_power_module.kicad_sch]
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2023-08-16 Fixed broken hardware addresses
    [zf_hardware.h]
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

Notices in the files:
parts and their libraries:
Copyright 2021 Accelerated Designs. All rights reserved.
